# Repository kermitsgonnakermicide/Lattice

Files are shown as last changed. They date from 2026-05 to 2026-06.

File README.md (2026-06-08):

# Lattice
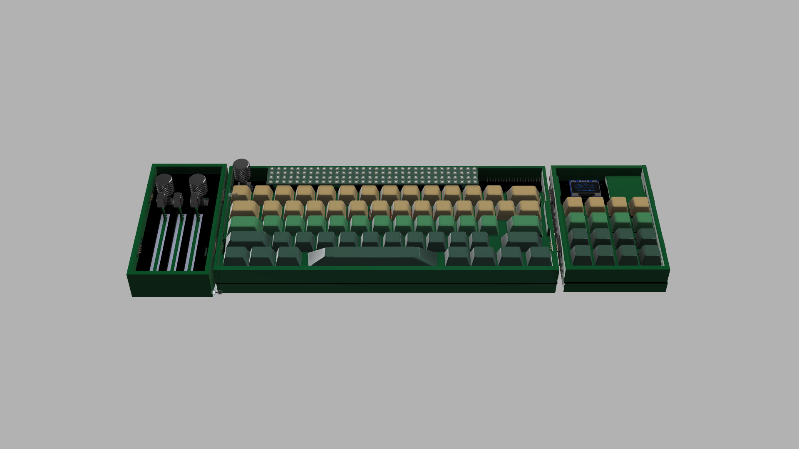
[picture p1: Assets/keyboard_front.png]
keyboard

> a 60% mechanical keyboard with magnetically attached modules

# what even is Lattice?
Lattice is a modular 60% mechanical keyboard, with the main keyboard featuring:
- cherry mx black switches
- a raspberry pi pico 2
- an EC11 encoder
- 6 expansion ports(two 2.54 inch female headers and 4 4 pin magnetic pogo connectors)
- absolutely NO RGB(in the keyboard itself skdsks)

Lattice also comes with three modules(as of now), which are:
- a 16 key macropad with an OLED
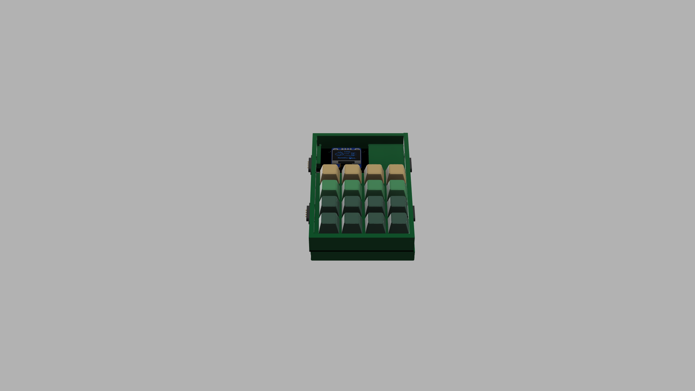
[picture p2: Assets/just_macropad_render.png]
macropad

- a 3 slider, two encoder module i'm calling the sliderpad
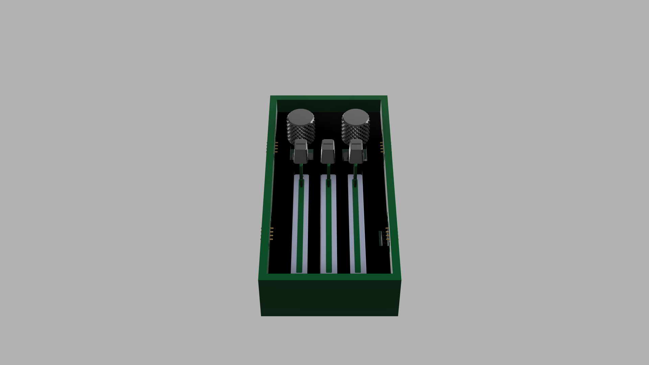
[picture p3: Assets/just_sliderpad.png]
sliderpad

- a 32x4 RGB LED(specifically the WS2812B-2020) matrix that slides in the empty top bit of the keyboard(connected by 2.54 mm pins because I didnt trust the current limits of the magnetic connectors)
matrix

Each module features a xiao rp2040 to run everything else on it because its so smol and cute :3</br>

The macropad and the sliderpad connect with magnetic pogo pins and use I2C to communicate with the main board, while the matrix does the same thing but just connects with normal pin headers and sockets. </br>

in terms of firmware, I have something basic for now - which runs each individual board and packs the data for I2C into a 16 bit struct - this wasnt really tracked as I lowk forgot and I used a bunch of AI so I wouldnt want track it anyways

# why did you even build this?(and many other whys)
I lowkenuinely just needed a keyboard pretty desperately - i've been using my crusty musty dusty redragon k552 for almost 5 years now and I need to switch it out :cryin:
additionally, I wanted a keyboard that I could actually take places, so things like a detachable cable(made possible by the pico 2) and a small form factor without compromising on key count was pretty important to me(hence the modules)

**Q: why xiao rp2040s on each board????**<br>
A: I can get them for hella cheap, they're really well documented, i've worked with them before and they're really small(works well for my purposes)

**Q: why not integrate a microcontroller on your board**<br>
A: while I would love to not use a module and put the straight microcontroller on this board, money is a problem here and I want to try and minimize costs where I can - a PCBA costs a crazy amount of money and with customs and shipping, this project aint covering it :cryin:

**Q: why not RGB?? are you not gamer???**<br>
A: i dont like RGB on the keeb - its annoying to work with, solder and must I remind you - **expensive** - to satiate the thirst for RGB i'm instead just slapping a giant matrix on the top empty bit of the board(hopefully playing snek on it soon)

# build instructions
- print out all PCBs from JLCPCB(only for the matrix PCB, use ENIG as you'll be soldering it yourself)
- get to soldering! a hot air gun/hotplate is reccomended for the matrix
- print out all parts in Production/Prints
- assemble with m3 nuts and bolts
- flash all xiao rp2040s and pico with micropython 
- on all, have boot.py and common.py and use the main.py in each folder for each respective bit 
- connect together and to your computer and start typing!
# images
<details>
<summary> Schematics </summary>

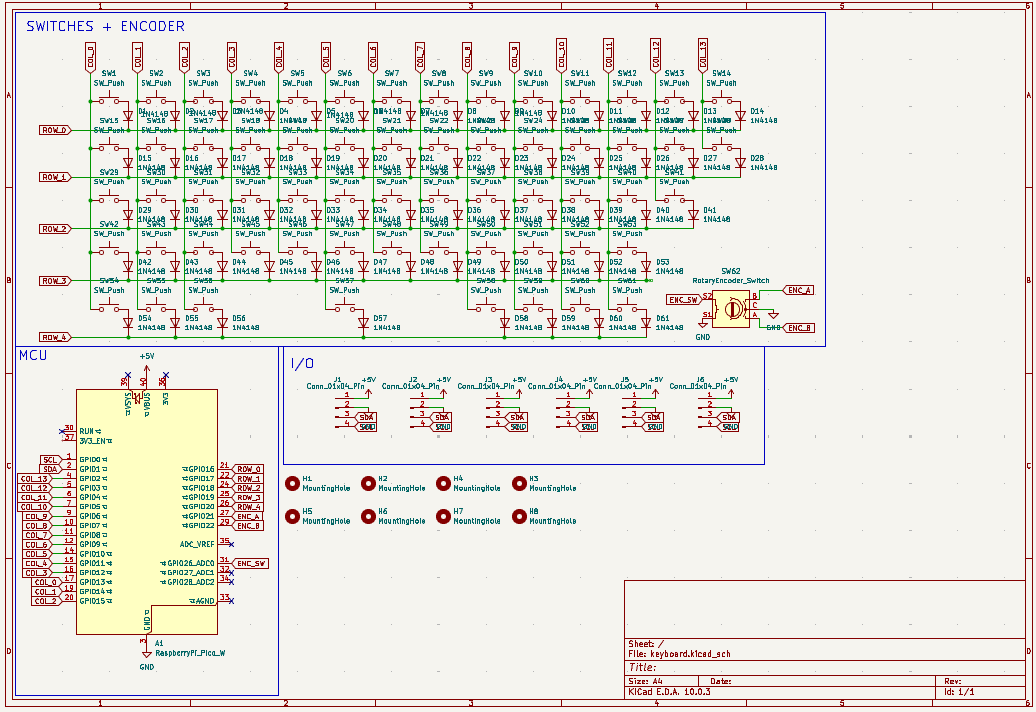
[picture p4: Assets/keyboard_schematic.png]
keyboard schematic

> main keyboard

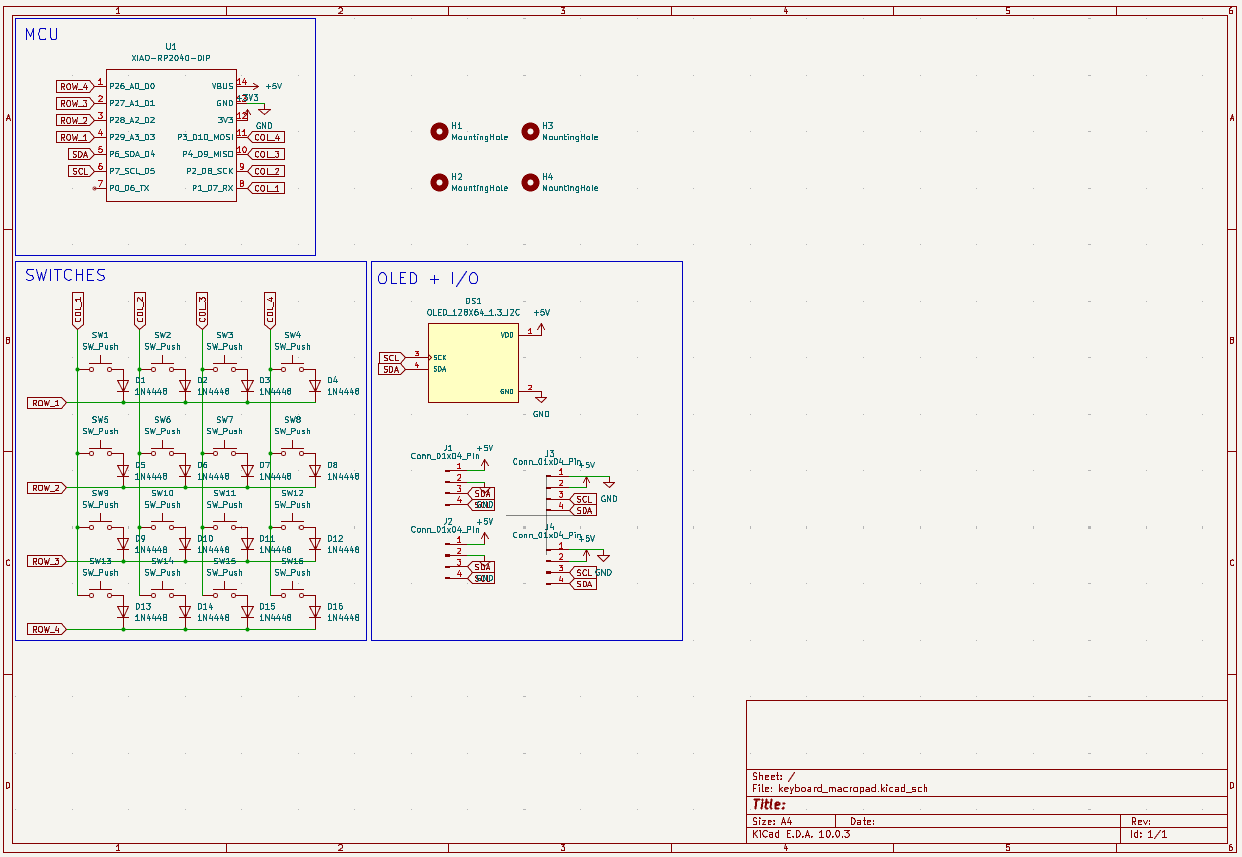
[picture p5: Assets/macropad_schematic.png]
macropad_schematic

>macropad 

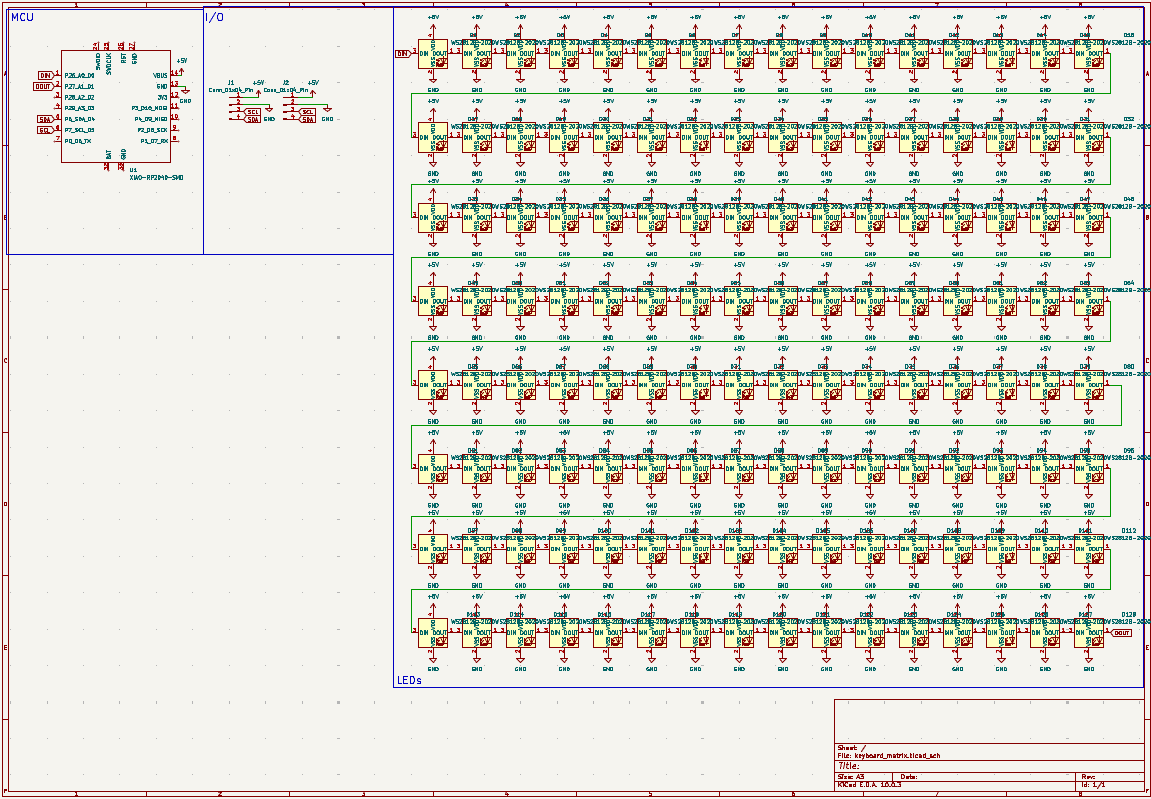
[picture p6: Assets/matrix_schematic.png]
sliderpad schematic

> sliderpad

matrix_schematic
> matrix

</details>

<details>

<summary> PCBs </summary>

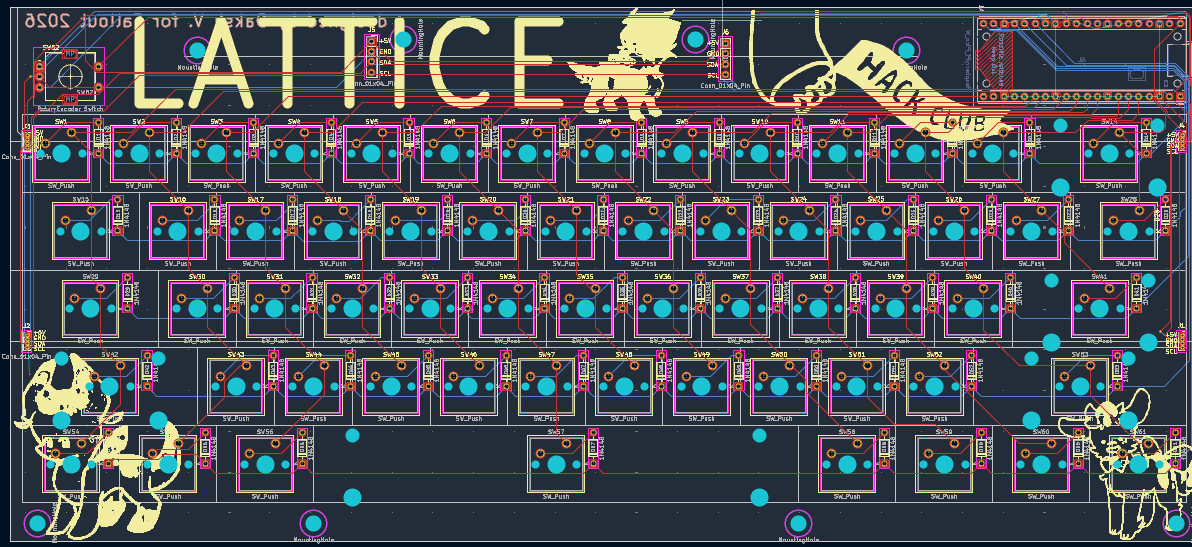
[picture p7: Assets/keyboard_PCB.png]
keyboard pcb

> main keyboard

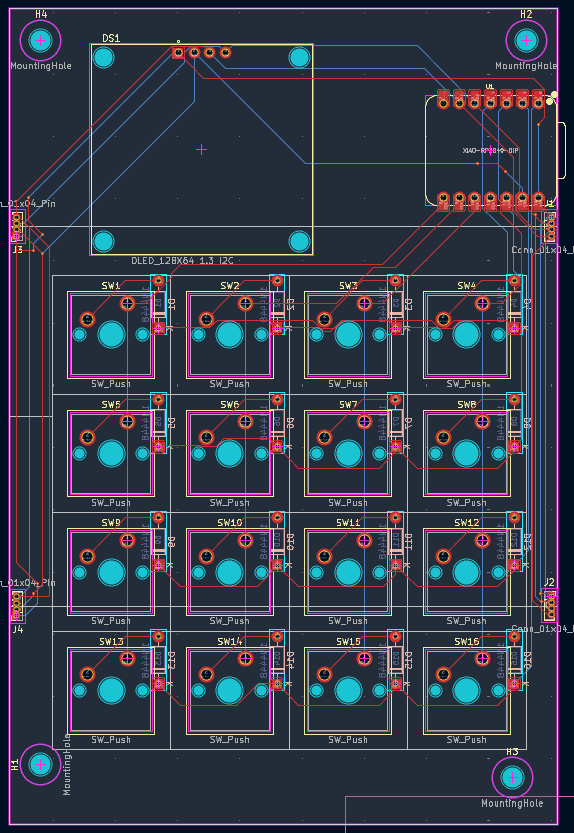
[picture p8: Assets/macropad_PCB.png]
macropad pcb

> macropad

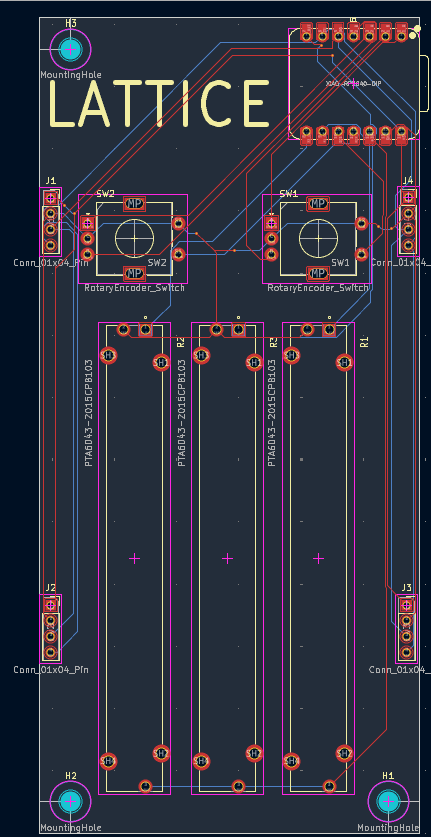
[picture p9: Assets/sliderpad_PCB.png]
sliderpad PCB

> sliderpad

matrix_pcb
> LED matrix

</details>

<details>

<summary> 3D models </summary>

keyboard pcb
> main keyboard

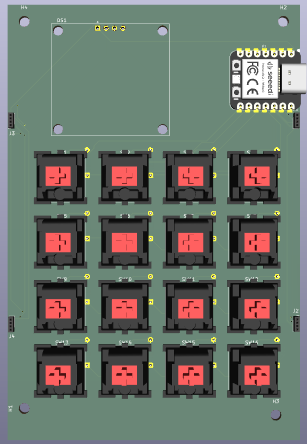
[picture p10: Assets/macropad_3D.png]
macropad pcb

> macropad

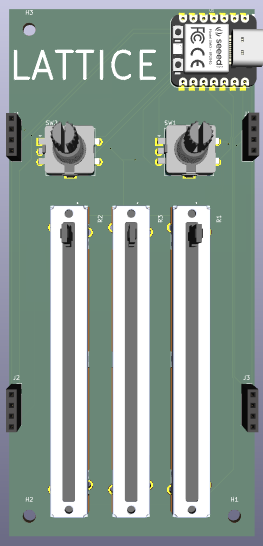
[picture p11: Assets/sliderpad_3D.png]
sliderpad PCB

> sliderpad

matrix_pcb
> LED matrix

</details>

<details>

<summary> CAD renders </summary>

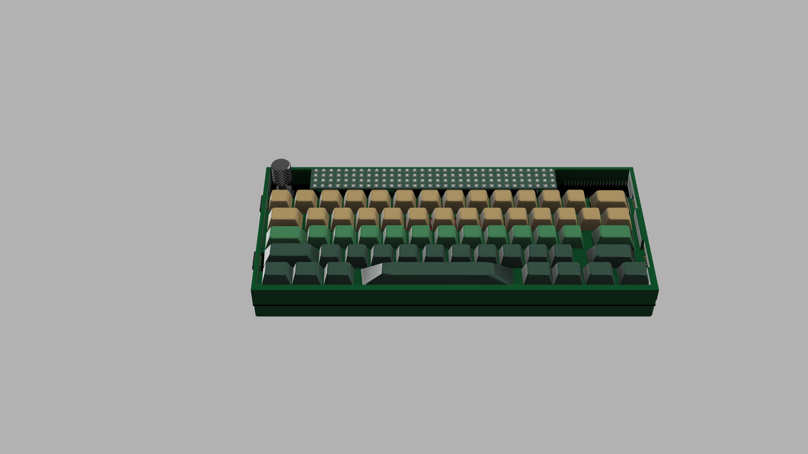
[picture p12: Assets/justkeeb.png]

> main keyboard

macropad pcb
> macropad

sliderpad PCB
> sliderpad

whole thing together
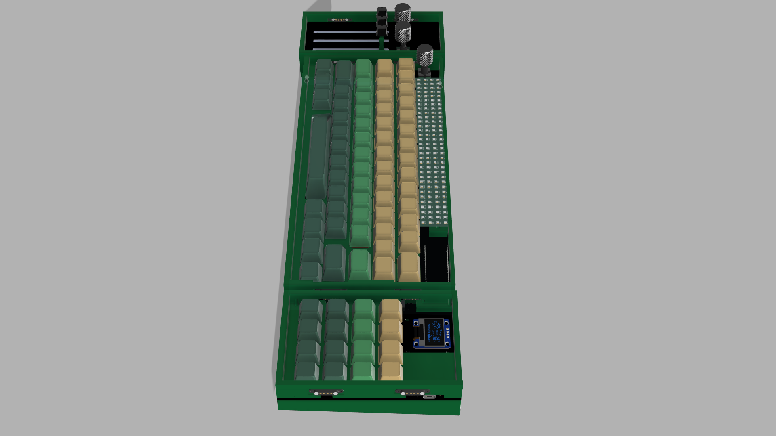
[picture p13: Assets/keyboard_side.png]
another angle

> the assembled keyboard!

</details>

# Zine

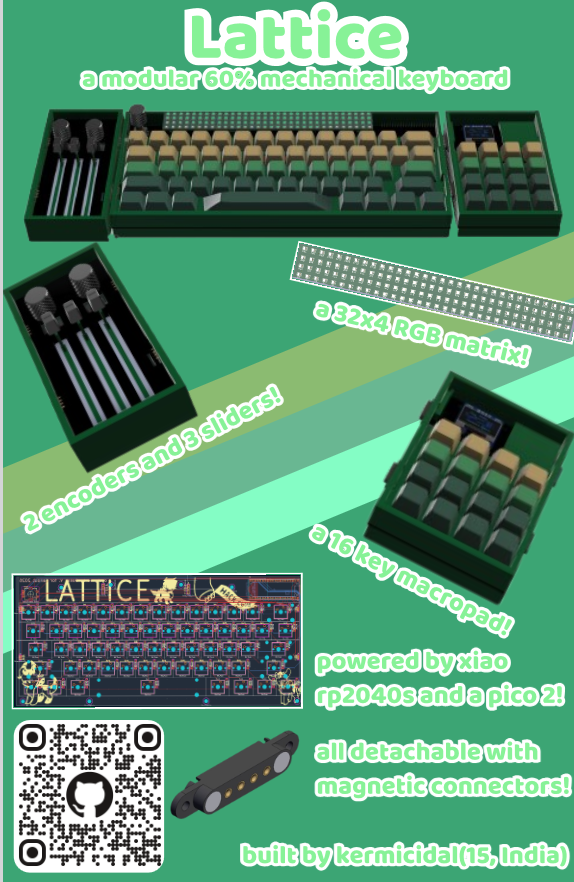
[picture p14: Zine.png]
zine


# BOM
| ITEM | LINK | UNIT PRICE | QTY  | TOTAL PRICE | RUNNING TOTAL | NOTES |
| --- | --- | --- | ---- | --- | --- | --- |
| Cherry MX Black Switches | [https://neomacro.in/products/cherry-mx-switches](https://neomacro.in/products/cherry-mx-switches) | 3.51 | 8 | 28.08 | 28.08 | pack of 10 |
| Keycap Set | [https://meckeys.com/shop/accessories/keyboard-accessories/keycaps/white-grey-keycaps/](https://meckeys.com/shop/accessories/keyboard-accessories/keycaps/white-grey-keycaps/) | 10.49 | 1 | 10.49 | 38.57 | for keyboard |
| Blank Keycaps | [https://meckeys.com/shop/accessories/keyboard-accessories/keycaps/blank/blank-dsa-keycaps-1u/](https://meckeys.com/shop/accessories/keyboard-accessories/keycaps/blank/blank-dsa-keycaps-1u/) | 1.05 | 4 | 4.2 | 42.77 | for macropad, will re-use hackpad keycaps |
| EC11 Encoders | [https://www.amazon.in/CentIoT-Encoder-Digital-Potentiometer-Control/dp/B0888RWNM1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](https://www.amazon.in/CentIoT-Encoder-Digital-Potentiometer-Control/dp/B0888RWNM1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) | 1.8 | 3 | 5.4 | 48.17 | already have |
| Slide Potentiometers | [https://www.amazon.in/Electronic-Spices-SC6080GH-Channel-Potentiometer/dp/B0BGY5C2KV?th=1](https://www.amazon.in/Electronic-Spices-SC6080GH-Channel-Potentiometer/dp/B0BGY5C2KV?th=1) | 3 | 1.68 | 5.04 | 53.21 | amazon is unfortunately the cheapest and most reliable place >:( |
| OLED | [https://robu.in/product/0-96-inch-i2c-iic-oled-lcd-module-4pin-with-vcc-gnd-blue/](https://robu.in/product/0-96-inch-i2c-iic-oled-lcd-module-4pin-with-vcc-gnd-blue/) | 2.14 | 1 | 2.14 | 55.35 | already have |
| 1N4148 diodes | [https://robu.in/product/1n4148-1w-zener-diode-pack-of-50/](https://robu.in/product/1n4148-1w-zener-diode-pack-of-50/) | 0.013 | 80 | 1.04 | 56.39 | |
| PCB | JLCPCB | 82.42 | 1 | 82.42 | 138.81 | |
| Xiao RP2040 | [https://thinkrobotics.com/products/seeed-studio-xiao-rp2040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](https://thinkrobotics.com/products/seeed-studio-xiao-rp2040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) | 5.77 | 3 | 17.31 | 156.12 | already have 2 |
| Pico 2 | [https://robu.in/product/raspberry-pi-pico-2/](https://robu.in/product/raspberry-pi-pico-2/) | 5.7 | 1 | 5.7 | 161.82 | already have 2 |
| WS2812B | [https://hubtronics.in/ws2812b-2020](https://hubtronics.in/ws2812b-2020) | 0.06 | 128  | 7.68 | 169.5 | |
| 4 pin magnetic connector pair | [https://www.flyrobo.in/4pin-pogo-magnetic-connector-pair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](https://www.flyrobo.in/4pin-pogo-magnetic-connector-pair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) | 2.06 | 4 | 8.24 | 177.74 | |
| TOTAL | | | | 0 | 177.74 | |

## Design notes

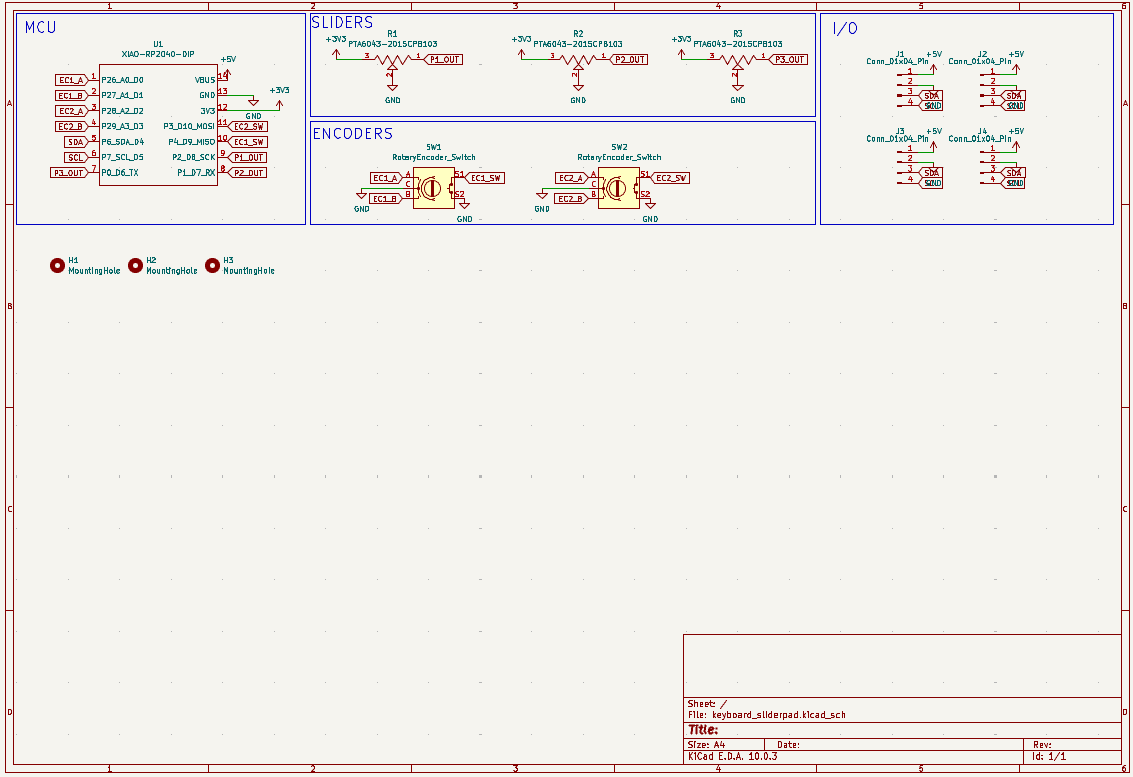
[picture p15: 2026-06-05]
Assets/sliderpad_schematic.png

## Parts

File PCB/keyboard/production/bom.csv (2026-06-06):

Designator | Footprint | Quantity | Value | LCSC Part #
A1 | RaspberryPi_Pico_Common_THT | 1 | RaspberryPi_Pico_W
D1, D10, D11, D12, D13, D14, D15, D16, D17, D18, D19, D2, D20, D21, D22, D23, D24, D25, D26, D27, D28, D29, D3, D30, D31, D32, D33, D34, D35, D36, D37, D38, D39, D4, D40, D41, D42, D43, D44, D45, D46, D47, D48, D49, D5, D50, D51, D52, D53, D54, D55, D56, D57, D58, D59, D6, D60, D61, D7, D8, D9 | D_DO-35_SOD27_P7.62mm_Horizontal | 61 | 1N4148
J1, J2, J3, J4 | PinSocket_1x04_P1.00mm_Vertical | 4 | Conn_01x04_Pin
J5, J6 | PinSocket_1x04_P2.54mm_Vertical | 2 | Conn_01x04_Pin
SW1, SW10, SW11, SW12, SW13, SW16, SW17, SW18, SW19, SW2, SW20, SW21, SW22, SW23, SW24, SW25, SW26, SW27, SW3, SW30, SW31, SW32, SW33, SW34, SW35, SW36, SW37, SW38, SW39, SW4, SW40, SW43, SW44, SW45, SW46, SW47, SW48, SW49, SW5, SW50, SW51, SW52, SW6, SW7, SW8, SW9 | jiggupiggu | 46 | SW_Push
SW14 | SW_Cherry_MX_2.00u_PCB | 1 | SW_Push
SW15, SW28 | SW_Cherry_MX_1.50u_PCB | 2 | SW_Push
SW29 | SW_Cherry_MX_1.75u_PCB | 1 | SW_Push
SW41, SW42 | SW_Cherry_MX_2.25u_PCB | 2 | SW_Push
SW53 | SW_Cherry_MX_2.75u_PCB | 1 | SW_Push
SW54, SW55, SW56, SW58, SW59, SW60, SW61 | SW_Cherry_MX_1.25u_PCB | 7 | SW_Push
SW57 | SW_Cherry_MX_6.25u_PCB | 1 | SW_Push
SW62 | RotaryEncoder_Alps_EC11E-Switch_Vertical_H20mm | 1 | RotaryEncoder_Switch

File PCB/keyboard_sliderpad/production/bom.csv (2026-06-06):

Designator | Footprint | Quantity | Value | LCSC Part #
J1, J2, J3, J4 | PinSocket_1x04_P2.54mm_Vertical | 4 | Conn_01x04_Pin
R1, R2, R3 | TRIM_PTA6043-2015CPB103 | 3 | PTA6043-2015CPB103
SW1, SW2 | RotaryEncoder_Alps_EC11E-Switch_Vertical_H20mm | 2 | RotaryEncoder_Switch
U1 | XIAO-RP2040-DIP | 1 | XIAO-RP2040-DIP

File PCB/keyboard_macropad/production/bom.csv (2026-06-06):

Designator | Footprint | Quantity | Value | LCSC Part #
D1, D10, D11, D12, D13, D14, D15, D16, D2, D3, D4, D5, D6, D7, D8, D9 | D_DO-35_SOD27_P7.62mm_Horizontal | 16 | 1N4448
DS1 | LCD_OLED_128X64_1.3_I2C | 1 | OLED_128X64_1.3_I2C
J1, J2, J3, J4 | PinSocket_1x04_P1.00mm_Vertical | 4 | Conn_01x04_Pin
SW1, SW10, SW11, SW12, SW13, SW14, SW15, SW16, SW2, SW3, SW4, SW5, SW6, SW7, SW8, SW9 | jiggupiggu | 16 | SW_Push
U1 | XIAO-RP2040-DIP | 1 | XIAO-RP2040-DIP

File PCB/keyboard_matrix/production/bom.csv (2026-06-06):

Designator | Footprint | Quantity | Value | LCSC Part #
D1, D10, D100, D101, D102, D103, D104, D105, D106, D107, D108, D109, D11, D110, D111, D112, D113, D114, D115, D116, D117, D118, D119, D12, D120, D121, D122, D123, D124, D125, D126, D127, D128, D13, D14, D15, D16, D17, D18, D19, D2, D20, D21, D22, D23, D24, D25, D26, D27, D28, D29, D3, D30, D31, D32, D33, D34, D35, D36, D37, D38, D39, D4, D40, D41, D42, D43, D44, D45, D46, D47, D48, D49, D5, D50, D51, D52, D53, D54, D55, D56, D57, D58, D59, D6, D60, D61, D62, D63, D64, D65, D66, D67, D68, D69, D7, D70, D71, D72, D73, D74, D75, D76, D77, D78, D79, D8, D80, D81, D82, D83, D84, D85, D86, D87, D88, D89, D9, D90, D91, D92, D93, D94, D95, D96, D97, D98, D99 | updatediddy | 128 | WS2812B-2020
J1, J2 | PinHeader_1x04_P2.54mm_Vertical_SMD_Pin1Right | 2 | Conn_01x04_Pin
U1 | XIAO-RP2040-SMD | 1 | XIAO-RP2040-SMD

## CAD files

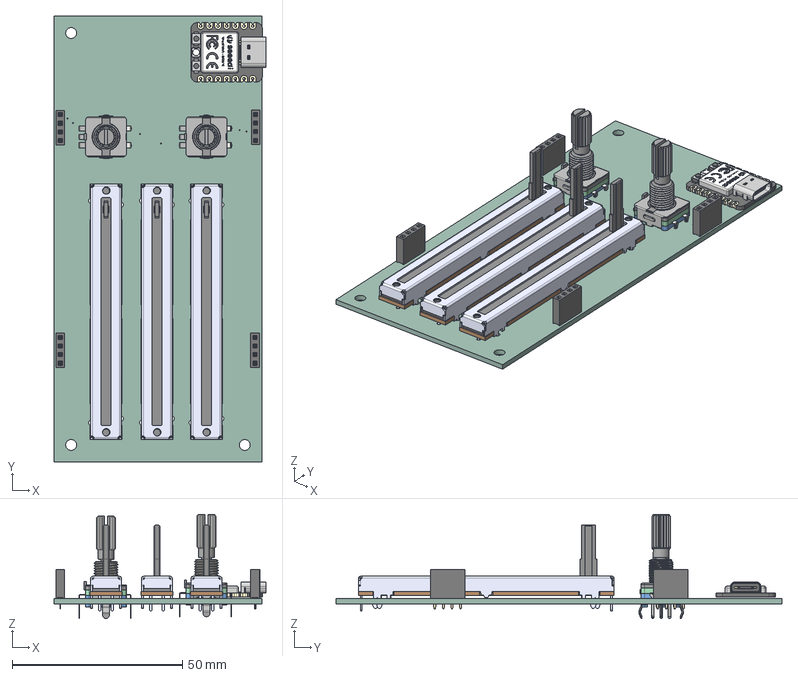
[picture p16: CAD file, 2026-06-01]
CAD/keyboard_sliderpad.step
62.2 x 131.0 x 30.6 mm
60315CP x 3
EC11_Rotary_Encoder_Switched x 2
type-c v2
smd_button v3
DOUT
DIN
VSS
VDD
smd_button v3(Mirror)
PinSocket_1x04_P2.54mm_Vertical x 4
keyboard_sliderpad_PCB

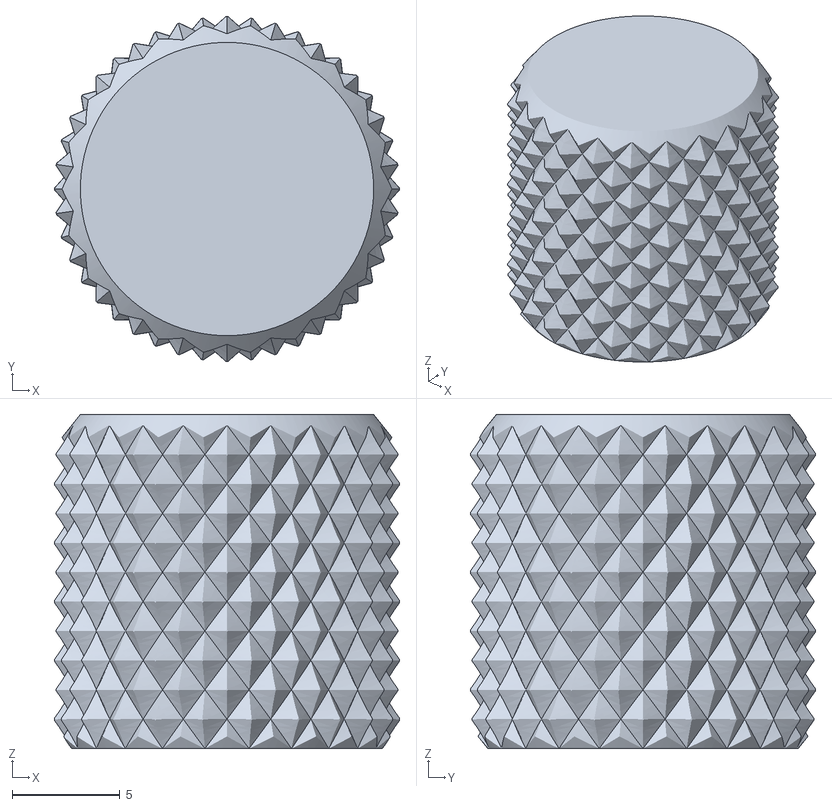
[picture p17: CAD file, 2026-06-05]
Production/Prints/rotaryKnobencoder_cap.stl
16.0 x 16.0 x 15.5

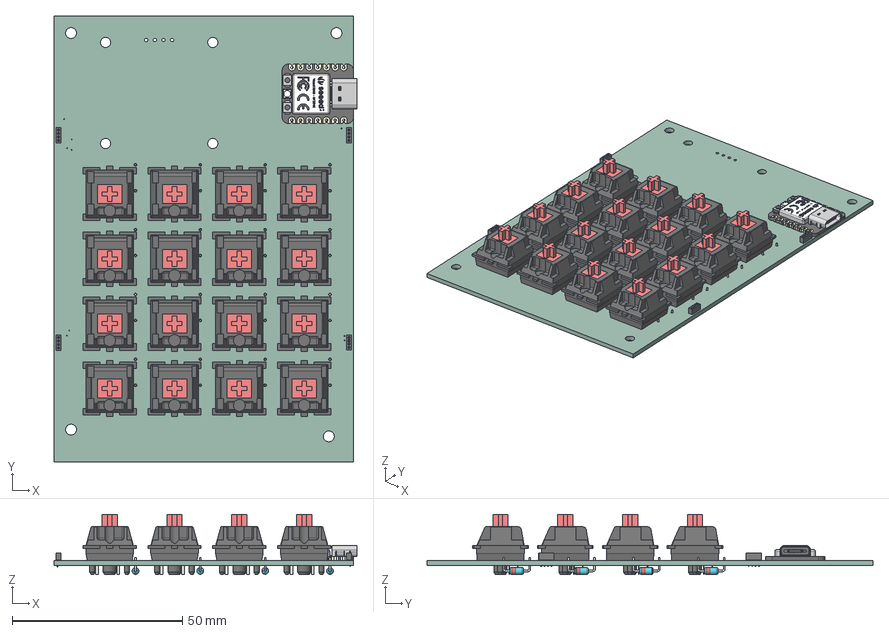
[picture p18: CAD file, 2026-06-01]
CAD/keyboard_macropad.step
89.0 x 131.0 x 17.7 mm
type-c v2
smd_button v3
DOUT
DIN
VSS
VDD
smd_button v3(Mirror)
PinSocket_1x04_P1.00mm_Vertical x 4
D_DO-35_SOD27_P7.62mm_Horizontal x 16
keyboard_macropad_PCB

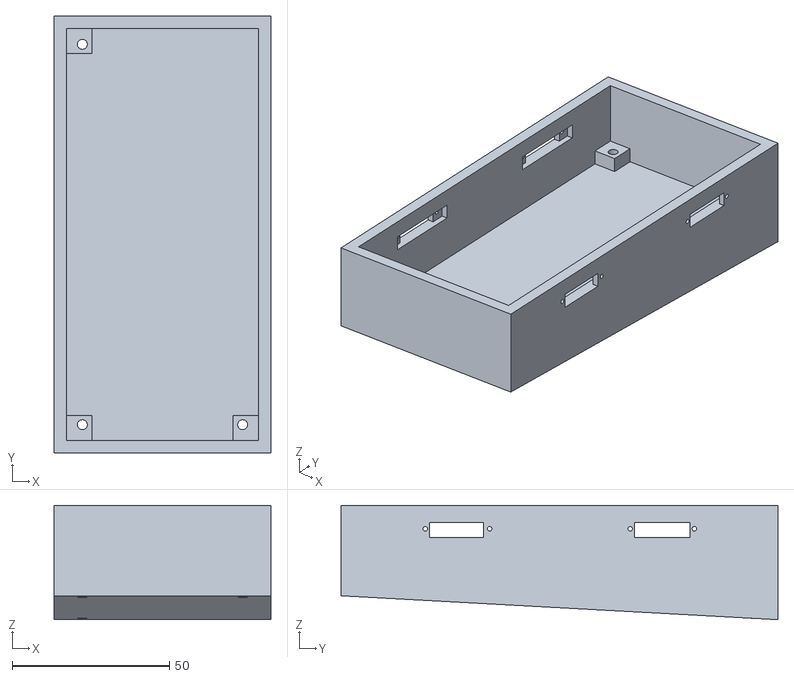
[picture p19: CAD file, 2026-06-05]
Production/Prints/sliderpad_bottomplate.stl
69.0 x 139.0 x 36.4

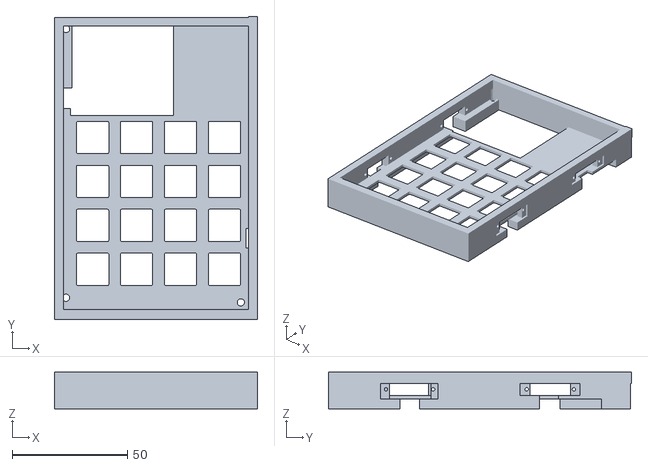
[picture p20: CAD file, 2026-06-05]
Production/Prints/macropad_topplate.stl
88.0 x 131.5 x 16.0

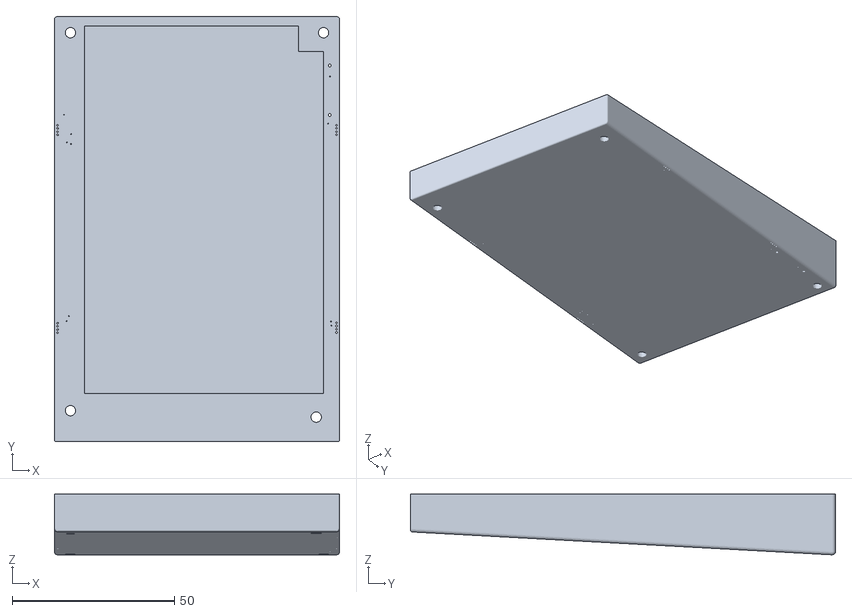
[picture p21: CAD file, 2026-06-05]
Production/Prints/macropad_bottom.stl
88.0 x 131.0 x 18.7

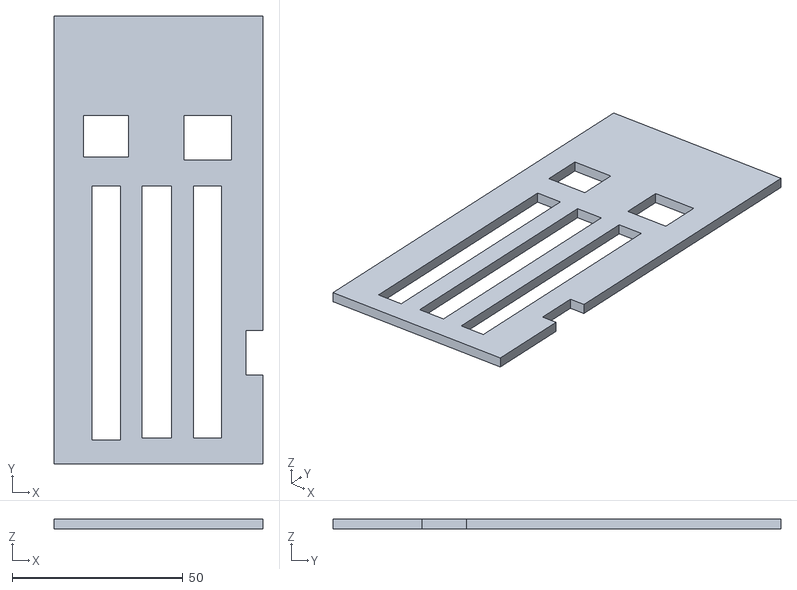
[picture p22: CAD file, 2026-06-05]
Production/Prints/sliderpad_topplate.stl
61.0 x 131.0 x 3.00

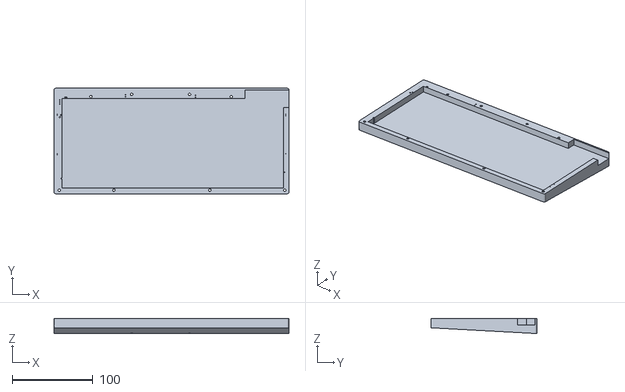
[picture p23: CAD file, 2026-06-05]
Production/Prints/keyboard_bottomplate.stl
291.4 x 131.0 x 18.7

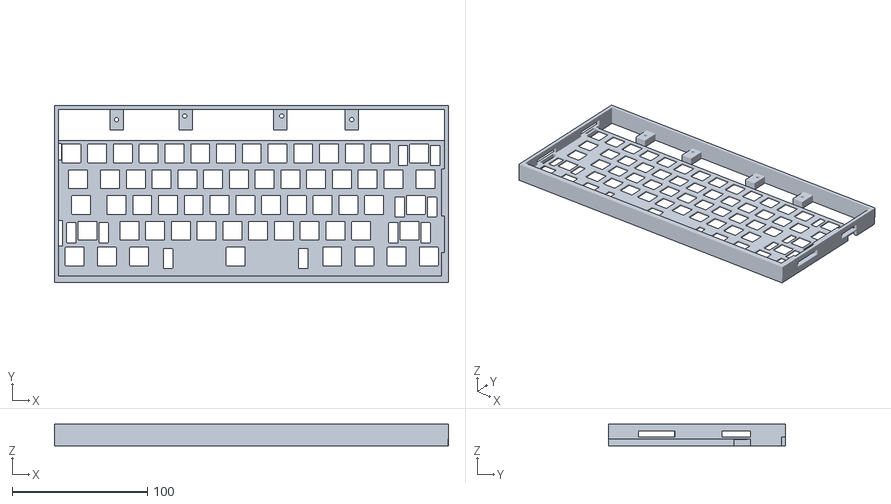
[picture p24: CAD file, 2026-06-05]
Production/Prints/keyboard_topplate.stl
291.4 x 131.0 x 16.0

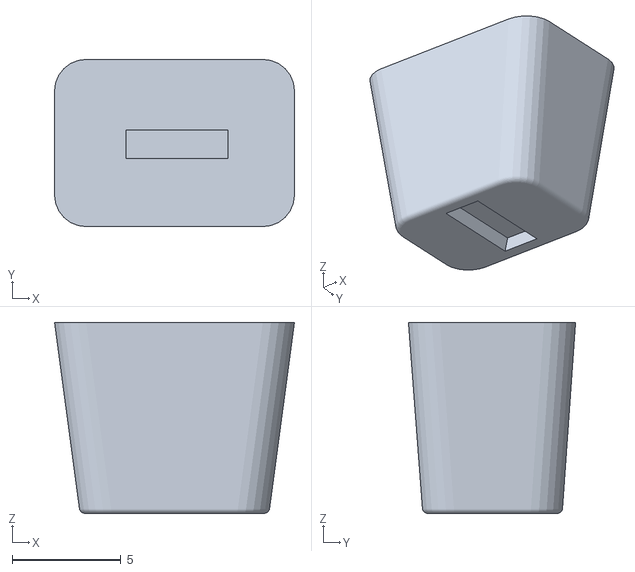
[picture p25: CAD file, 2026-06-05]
Production/Prints/001_sliderknob_v07.stl
11.0 x 7.67 x 8.78

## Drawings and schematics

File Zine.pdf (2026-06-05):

# Lattice

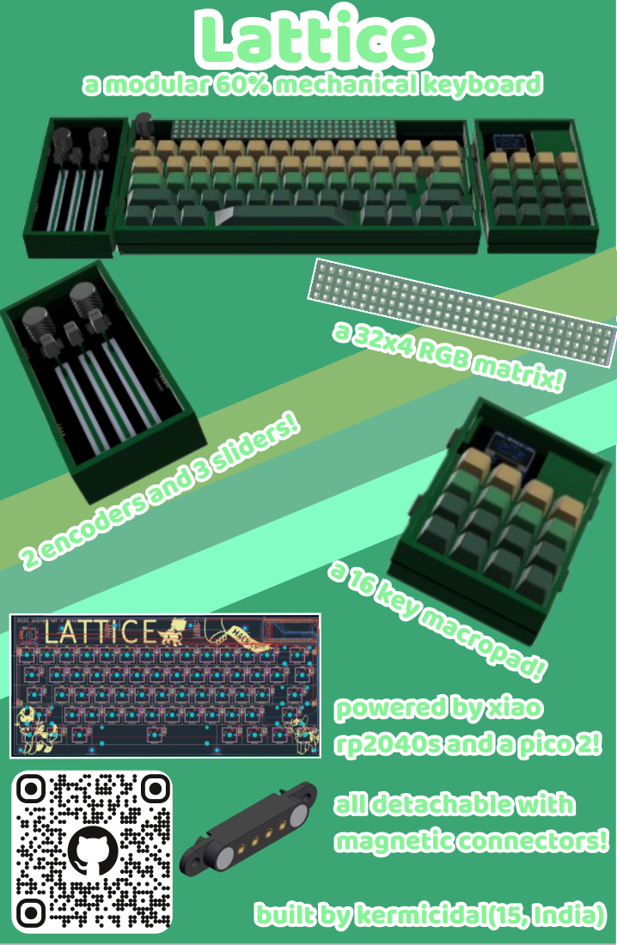
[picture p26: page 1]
a 16 key macropad!; rp2040s and a pico 2!; a 32x4 RGB matrix!; magnetic connectors!

a modular 60% mechanical keyboard

2 encoders and 3 sliders!

powered by xiao

all detachable with

built by kermicidal(15, India)

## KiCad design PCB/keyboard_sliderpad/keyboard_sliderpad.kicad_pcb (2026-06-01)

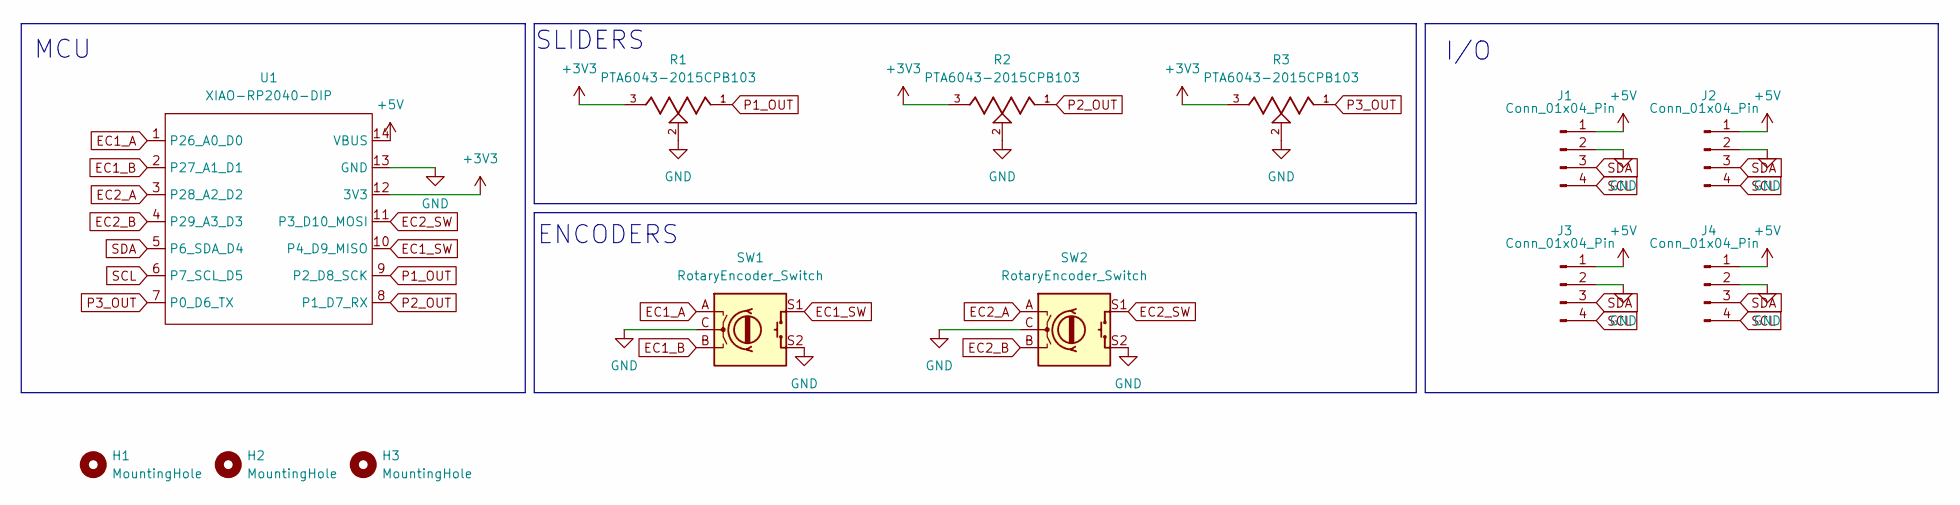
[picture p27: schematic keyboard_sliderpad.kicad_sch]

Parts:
H1, H2, H3: MountingHole; MountingHole_3.2mm_M3
J1, J2, J3, J4: Conn_01x04_Pin; PinSocket_1x04_P2.54mm_Vertical
R1, R2, R3: PTA6043-2015CPB103; TRIM_PTA6043-2015CPB103; PARTREV 04/21
SW1, SW2: RotaryEncoder_Switch; RotaryEncoder_Alps_EC11E-Switch_Vertical_H20mm
U1: XIAO-RP2040-DIP

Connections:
+3V3: R1.3, R2.3, R3.3, U1.12 (3V3)
+5V: J1.1, J2.1, J3.1, J4.1, U1.14 (VBUS)
EC1_A: SW1.A, U1.1 (P26_A0_D0)
EC1_B: SW1.B, U1.2 (P27_A1_D1)
EC1_SW: SW1.S1, U1.10 (P4_D9_MISO)
EC2_A: SW2.A, U1.3 (P28_A2_D2)
EC2_B: SW2.B, U1.4 (P29_A3_D3)
EC2_SW: SW2.S1, U1.11 (P3_D10_MOSI)
GND: J1.2, J2.2, J3.2, J4.2, R1.2, R2.2, R3.2, SW1.C, SW1.S2, SW2.C, SW2.S2, U1.13 (GND)
P1_OUT: R1.1, U1.9 (P2_D8_SCK)
P2_OUT: R2.1, U1.8 (P1_D7_RX)
P3_OUT: R3.1, U1.7 (P0_D6_TX)
SCL: J1.4, J2.4, J3.4, J4.4, U1.6 (P7_SCL_D5)
SDA: J1.3, J2.3, J3.3, J4.3, U1.5 (P6_SDA_D4)

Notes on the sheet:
MCU
SLIDERS
I/O
ENCODERS

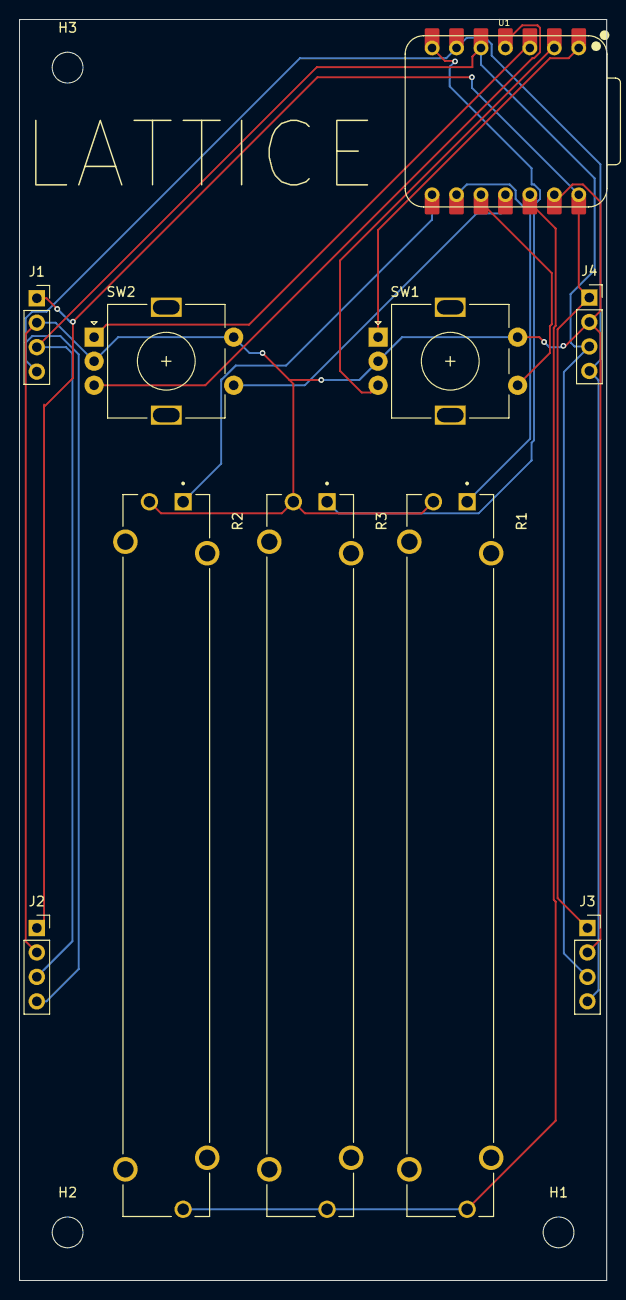
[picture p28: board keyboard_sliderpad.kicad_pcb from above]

Board: 2 copper layers, 61.0 x 131.0 mm, 13 parts (0 on the bottom side), 14 nets.

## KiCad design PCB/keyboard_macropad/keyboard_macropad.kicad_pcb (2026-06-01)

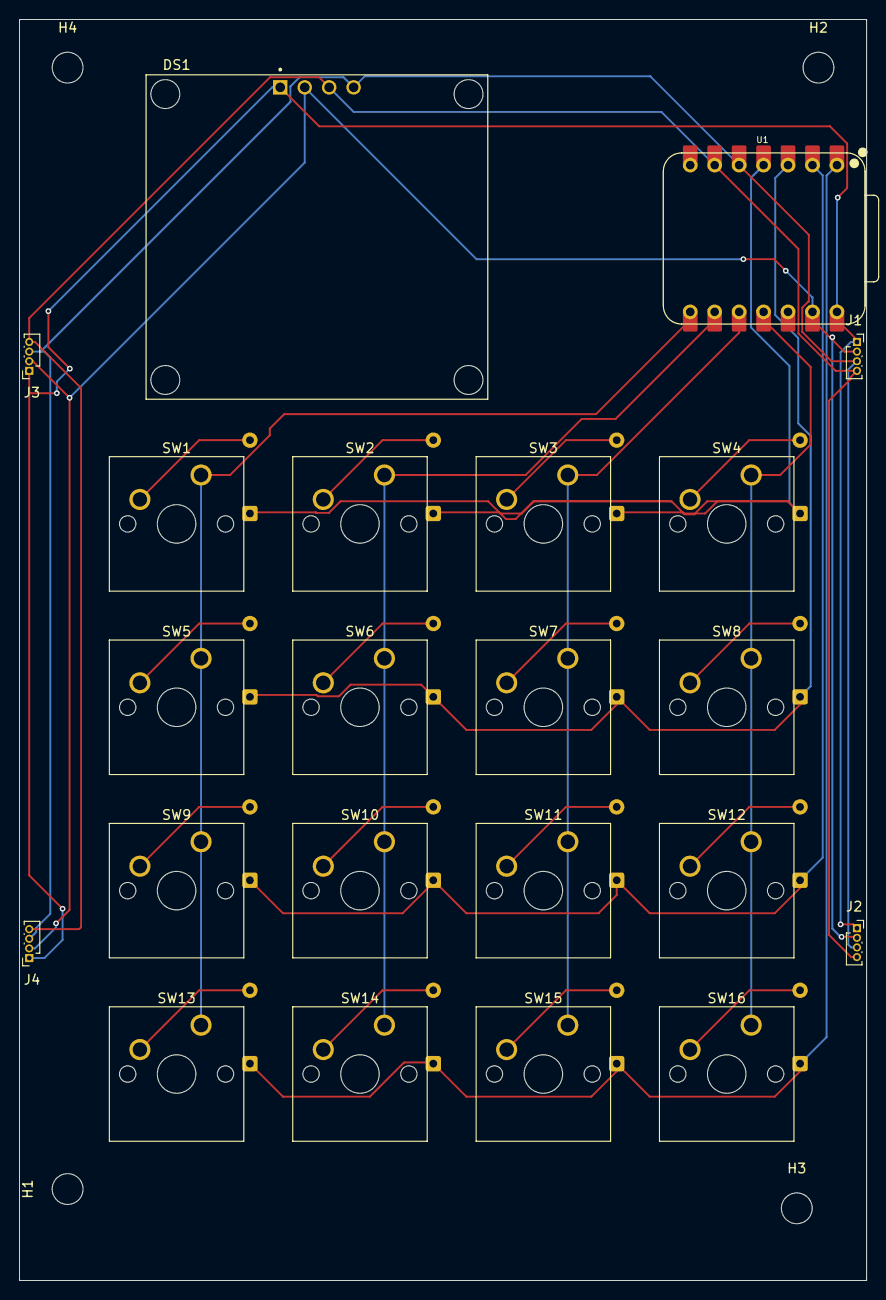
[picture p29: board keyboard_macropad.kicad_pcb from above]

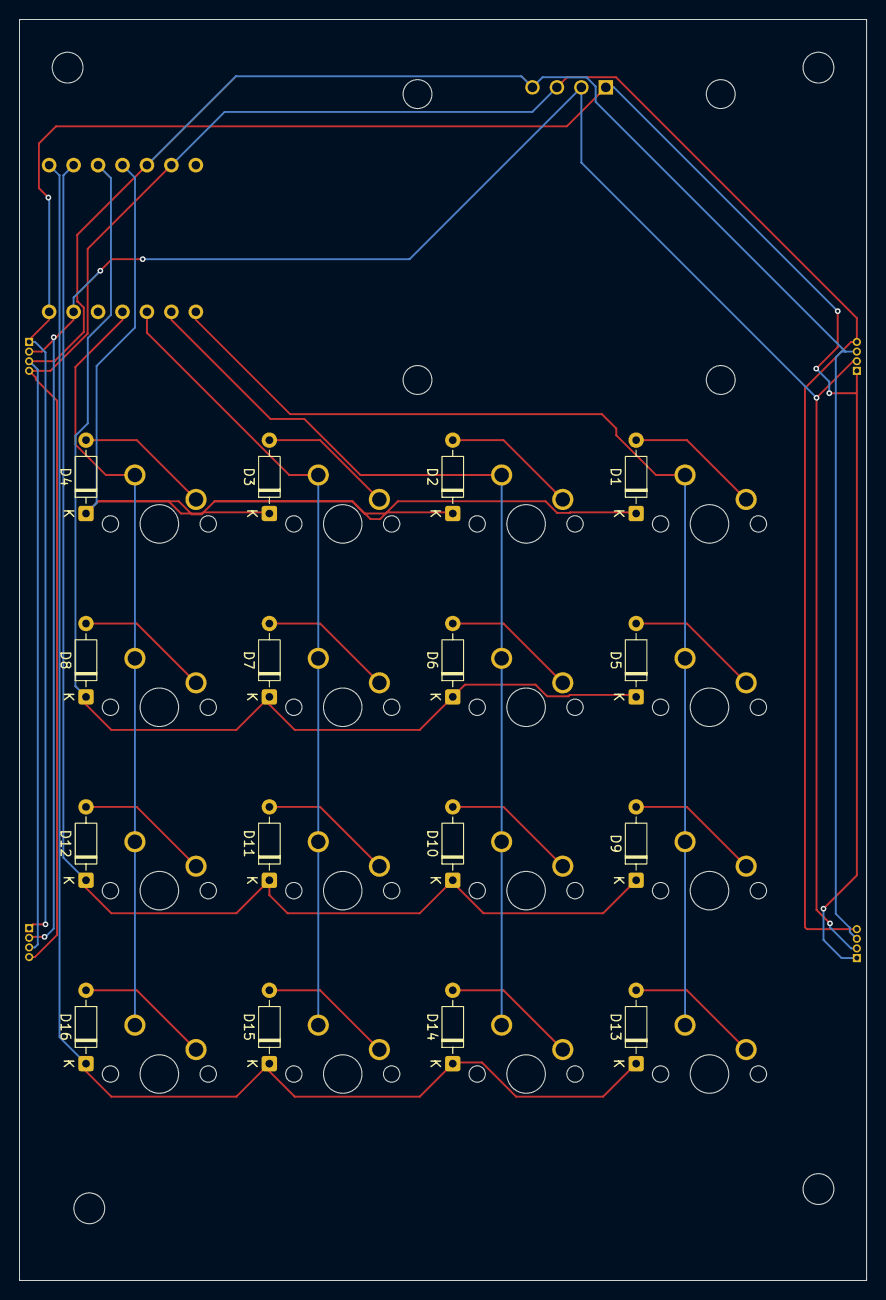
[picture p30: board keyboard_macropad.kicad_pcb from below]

Board: 2 copper layers, 88.0 x 131.0 mm, 42 parts (16 on the bottom side), 28 nets.

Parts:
D1, D2, D3, D4, D5, D6, D7, D8, D9, D10, D11, D12, D13, D14, D15, D16: 1N4448; D_DO-35_SOD27_P7.62mm_Horizontal
DS1: OLED_128X64_1.3_I2C; LCD_OLED_128X64_1.3_I2C
H1, H2, H3, H4: MountingHole; MountingHole_3.2mm_M3
J1, J2, J3, J4: Conn_01x04_Pin; PinSocket_1x04_P1.00mm_Vertical
SW1, SW2, SW3, SW4, SW5, SW6, SW7, SW8, SW9, SW10, SW11, SW12, SW13, SW14, SW15, SW16: SW_Push; jiggupiggu
U1: XIAO-RP2040-DIP

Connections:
+5V: DS1.1 (VDD), J1.1, J2.1, J3.1, J4.1, U1.14 (VBUS)
COL_1: SW1.1, SW5.1, SW9.1, SW13.1, U1.8 (P1_D7_RX)
COL_2: SW2.1, SW6.1, SW10.1, SW14.1, U1.9 (P2_D8_SCK)
COL_3: SW3.1, SW7.1, SW11.1, SW15.1, U1.10 (P4_D9_MISO)
COL_4: SW4.1, SW8.1, SW12.1, SW16.1, U1.11 (P3_D10_MOSI)
GND: DS1.2 (GND), J1.2, J2.2, J3.2, J4.2, U1.13 (GND)
unnamed: D1.2 (A), SW1.2
unnamed: D2.2 (A), SW2.2
unnamed: D3.2 (A), SW3.2
unnamed: D4.2 (A), SW4.2
unnamed: D5.2 (A), SW5.2
unnamed: D6.2 (A), SW6.2
unnamed: D7.2 (A), SW7.2
unnamed: D8.2 (A), SW8.2
unnamed: D9.2 (A), SW9.2
unnamed: D10.2 (A), SW10.2
unnamed: D11.2 (A), SW11.2
unnamed: D12.2 (A), SW12.2
unnamed: D13.2 (A), SW13.2
unnamed: D14.2 (A), SW14.2
unnamed: D15.2 (A), SW15.2
unnamed: D16.2 (A), SW16.2
ROW_1: D1.1 (K), D2.1 (K), D3.1 (K), D4.1 (K), U1.4 (P29_A3_D3)
ROW_2: D5.1 (K), D6.1 (K), D7.1 (K), D8.1 (K), U1.3 (P28_A2_D2)
ROW_3: D9.1 (K), D10.1 (K), D11.1 (K), D12.1 (K), U1.2 (P27_A1_D1)
ROW_4: D13.1 (K), D14.1 (K), D15.1 (K), D16.1 (K), U1.1 (P26_A0_D0)
SCL: DS1.3 (SCK), J1.4, J2.4, J3.4, J4.4, U1.6 (P7_SCL_D5)
SDA: DS1.4 (SDA), J1.3, J2.3, J3.3, J4.3, U1.5 (P6_SDA_D4)

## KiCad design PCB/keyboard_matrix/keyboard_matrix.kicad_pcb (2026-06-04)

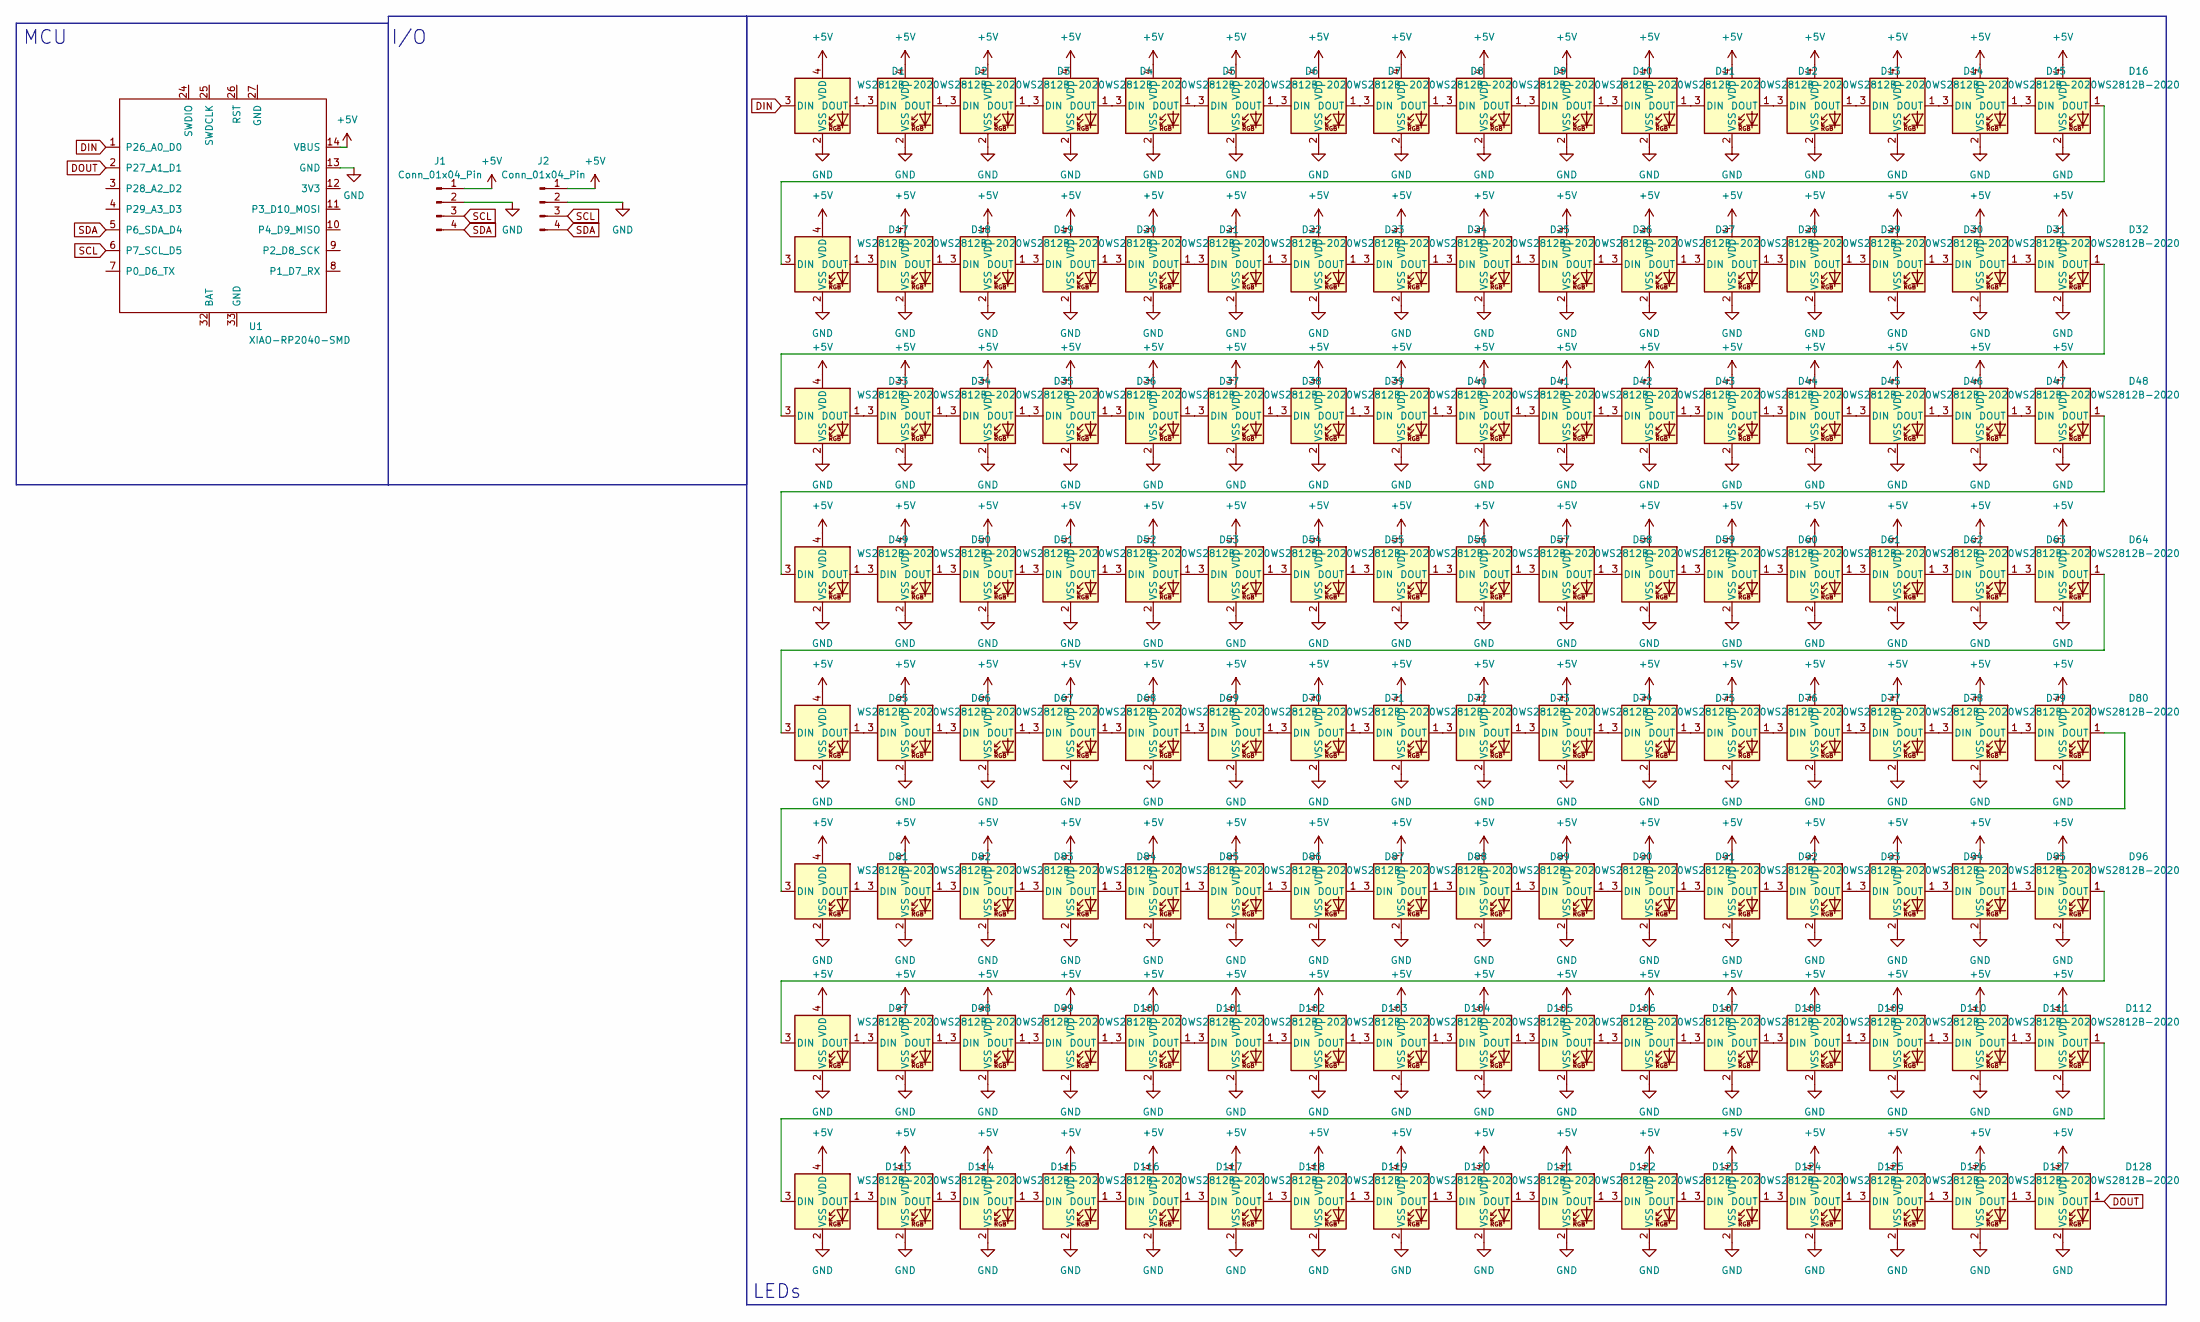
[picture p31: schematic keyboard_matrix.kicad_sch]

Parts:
D1, D2, D3, D4, D5, D6, D7, D8, D9, D10, D11, D12, D13, D14, D15, D16, D17, D18, D19, D20, D21, D22, D23, D24, D25, D26, D27, D28, D29, D30, D31, D32, D33, D34, D35, D36, D37, D38, D39, D40, D41, D42, D43, D44, D45, D46, D47, D48, D49, D50, D51, D52, D53, D54, D55, D56, D57, D58, D59, D60, D61, D62, D63, D64, D65, D66, D67, D68, D69, D70, D71, D72, D73, D74, D75, D76, D77, D78, D79, D80, D81, D82, D83, D84, D85, D86, D87, D88, D89, D90, D91, D92, D93, D94, D95, D96, D97, D98, D99, D100, D101, D102, D103, D104, D105, D106, D107, D108, D109, D110, D111, D112, D113, D114, D115, D116, D117, D118, D119, D120, D121, D122, D123, D124, D125, D126, D127, D128: WS2812B-2020; LED_WS2812B-2020_PLCC4_2.0x2.0mm
J1, J2: Conn_01x04_Pin; PinHeader_1x04_P2.54mm_Vertical_SMD_Pin1Right
U1: XIAO-RP2040-SMD

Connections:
+5V: D1.4 (VDD), D2.4 (VDD), D3.4 (VDD), D4.4 (VDD), D5.4 (VDD), D6.4 (VDD), D7.4 (VDD), D8.4 (VDD), D9.4 (VDD), D10.4 (VDD), D11.4 (VDD), D12.4 (VDD), D13.4 (VDD), D14.4 (VDD), D15.4 (VDD), D16.4 (VDD), D17.4 (VDD), D18.4 (VDD), D19.4 (VDD), D20.4 (VDD), D21.4 (VDD), D22.4 (VDD), D23.4 (VDD), D24.4 (VDD), D25.4 (VDD), D26.4 (VDD), D27.4 (VDD), D28.4 (VDD), D29.4 (VDD), D30.4 (VDD), D31.4 (VDD), D32.4 (VDD), D33.4 (VDD), D34.4 (VDD), D35.4 (VDD), D36.4 (VDD), D37.4 (VDD), D38.4 (VDD), D39.4 (VDD), D40.4 (VDD), D41.4 (VDD), D42.4 (VDD), D43.4 (VDD), D44.4 (VDD), D45.4 (VDD), D46.4 (VDD), D47.4 (VDD), D48.4 (VDD), D49.4 (VDD), D50.4 (VDD), D51.4 (VDD), D52.4 (VDD), D53.4 (VDD), D54.4 (VDD), D55.4 (VDD), D56.4 (VDD), D57.4 (VDD), D58.4 (VDD), D59.4 (VDD), D60.4 (VDD), D61.4 (VDD), D62.4 (VDD), D63.4 (VDD), D64.4 (VDD), D65.4 (VDD), D66.4 (VDD), D67.4 (VDD), D68.4 (VDD), D69.4 (VDD), D70.4 (VDD), D71.4 (VDD), D72.4 (VDD), D73.4 (VDD), D74.4 (VDD), D75.4 (VDD), D76.4 (VDD), D77.4 (VDD), D78.4 (VDD), D79.4 (VDD), D80.4 (VDD), D81.4 (VDD), D82.4 (VDD), D83.4 (VDD), D84.4 (VDD), D85.4 (VDD), D86.4 (VDD), D87.4 (VDD), D88.4 (VDD), D89.4 (VDD), D90.4 (VDD), D91.4 (VDD), D92.4 (VDD), D93.4 (VDD), D94.4 (VDD), D95.4 (VDD), D96.4 (VDD), D97.4 (VDD), D98.4 (VDD), D99.4 (VDD), D100.4 (VDD), D101.4 (VDD), D102.4 (VDD), D103.4 (VDD), D104.4 (VDD), D105.4 (VDD), D106.4 (VDD), D107.4 (VDD), D108.4 (VDD), D109.4 (VDD), D110.4 (VDD), D111.4 (VDD), D112.4 (VDD), D113.4 (VDD), D114.4 (VDD), D115.4 (VDD), D116.4 (VDD), D117.4 (VDD), D118.4 (VDD), D119.4 (VDD), D120.4 (VDD), D121.4 (VDD), D122.4 (VDD), D123.4 (VDD), D124.4 (VDD), D125.4 (VDD), D126.4 (VDD), D127.4 (VDD), D128.4 (VDD), J1.1, J2.1, U1.14 (VBUS)
DIN: D1.3 (DIN), U1.1 (P26_A0_D0)
DOUT: D128.1 (DOUT), U1.2 (P27_A1_D1)
GND: D1.2 (VSS), D2.2 (VSS), D3.2 (VSS), D4.2 (VSS), D5.2 (VSS), D6.2 (VSS), D7.2 (VSS), D8.2 (VSS), D9.2 (VSS), D10.2 (VSS), D11.2 (VSS), D12.2 (VSS), D13.2 (VSS), D14.2 (VSS), D15.2 (VSS), D16.2 (VSS), D17.2 (VSS), D18.2 (VSS), D19.2 (VSS), D20.2 (VSS), D21.2 (VSS), D22.2 (VSS), D23.2 (VSS), D24.2 (VSS), D25.2 (VSS), D26.2 (VSS), D27.2 (VSS), D28.2 (VSS), D29.2 (VSS), D30.2 (VSS), D31.2 (VSS), D32.2 (VSS), D33.2 (VSS), D34.2 (VSS), D35.2 (VSS), D36.2 (VSS), D37.2 (VSS), D38.2 (VSS), D39.2 (VSS), D40.2 (VSS), D41.2 (VSS), D42.2 (VSS), D43.2 (VSS), D44.2 (VSS), D45.2 (VSS), D46.2 (VSS), D47.2 (VSS), D48.2 (VSS), D49.2 (VSS), D50.2 (VSS), D51.2 (VSS), D52.2 (VSS), D53.2 (VSS), D54.2 (VSS), D55.2 (VSS), D56.2 (VSS), D57.2 (VSS), D58.2 (VSS), D59.2 (VSS), D60.2 (VSS), D61.2 (VSS), D62.2 (VSS), D63.2 (VSS), D64.2 (VSS), D65.2 (VSS), D66.2 (VSS), D67.2 (VSS), D68.2 (VSS), D69.2 (VSS), D70.2 (VSS), D71.2 (VSS), D72.2 (VSS), D73.2 (VSS), D74.2 (VSS), D75.2 (VSS), D76.2 (VSS), D77.2 (VSS), D78.2 (VSS), D79.2 (VSS), D80.2 (VSS), D81.2 (VSS), D82.2 (VSS), D83.2 (VSS), D84.2 (VSS), D85.2 (VSS), D86.2 (VSS), D87.2 (VSS), D88.2 (VSS), D89.2 (VSS), D90.2 (VSS), D91.2 (VSS), D92.2 (VSS), D93.2 (VSS), D94.2 (VSS), D95.2 (VSS), D96.2 (VSS), D97.2 (VSS), D98.2 (VSS), D99.2 (VSS), D100.2 (VSS), D101.2 (VSS), D102.2 (VSS), D103.2 (VSS), D104.2 (VSS), D105.2 (VSS), D106.2 (VSS), D107.2 (VSS), D108.2 (VSS), D109.2 (VSS), D110.2 (VSS), D111.2 (VSS), D112.2 (VSS), D113.2 (VSS), D114.2 (VSS), D115.2 (VSS), D116.2 (VSS), D117.2 (VSS), D118.2 (VSS), D119.2 (VSS), D120.2 (VSS), D121.2 (VSS), D122.2 (VSS), D123.2 (VSS), D124.2 (VSS), D125.2 (VSS), D126.2 (VSS), D127.2 (VSS), D128.2 (VSS), J1.2, J2.2, U1.13 (GND)
unnamed: D1.1 (DOUT), D2.3 (DIN)
unnamed: D2.1 (DOUT), D3.3 (DIN)
unnamed: D3.1 (DOUT), D4.3 (DIN)
unnamed: D4.1 (DOUT), D5.3 (DIN)
unnamed: D5.1 (DOUT), D6.3 (DIN)
unnamed: D6.1 (DOUT), D7.3 (DIN)
unnamed: D7.1 (DOUT), D8.3 (DIN)
unnamed: D8.1 (DOUT), D9.3 (DIN)
unnamed: D9.1 (DOUT), D10.3 (DIN)
unnamed: D10.1 (DOUT), D11.3 (DIN)
unnamed: D11.1 (DOUT), D12.3 (DIN)
unnamed: D12.1 (DOUT), D13.3 (DIN)
unnamed: D13.1 (DOUT), D14.3 (DIN)
unnamed: D14.1 (DOUT), D15.3 (DIN)
unnamed: D15.1 (DOUT), D16.3 (DIN)
unnamed: D16.1 (DOUT), D17.3 (DIN)
unnamed: D17.1 (DOUT), D18.3 (DIN)
unnamed: D18.1 (DOUT), D19.3 (DIN)
unnamed: D19.1 (DOUT), D20.3 (DIN)
unnamed: D20.1 (DOUT), D21.3 (DIN)
unnamed: D21.1 (DOUT), D22.3 (DIN)
unnamed: D22.1 (DOUT), D23.3 (DIN)
unnamed: D23.1 (DOUT), D24.3 (DIN)
unnamed: D24.1 (DOUT), D25.3 (DIN)
unnamed: D25.1 (DOUT), D26.3 (DIN)
unnamed: D26.1 (DOUT), D27.3 (DIN)
unnamed: D27.1 (DOUT), D28.3 (DIN)
unnamed: D28.1 (DOUT), D29.3 (DIN)
unnamed: D29.1 (DOUT), D30.3 (DIN)
unnamed: D30.1 (DOUT), D31.3 (DIN)
unnamed: D31.1 (DOUT), D32.3 (DIN)
unnamed: D32.1 (DOUT), D33.3 (DIN)
unnamed: D33.1 (DOUT), D34.3 (DIN)
unnamed: D34.1 (DOUT), D35.3 (DIN)
unnamed: D35.1 (DOUT), D36.3 (DIN)
unnamed: D36.1 (DOUT), D37.3 (DIN)
unnamed: D37.1 (DOUT), D38.3 (DIN)
unnamed: D38.1 (DOUT), D39.3 (DIN)
unnamed: D39.1 (DOUT), D40.3 (DIN)
unnamed: D40.1 (DOUT), D41.3 (DIN)
unnamed: D41.1 (DOUT), D42.3 (DIN)
unnamed: D42.1 (DOUT), D43.3 (DIN)
unnamed: D43.1 (DOUT), D44.3 (DIN)
unnamed: D44.1 (DOUT), D45.3 (DIN)
unnamed: D45.1 (DOUT), D46.3 (DIN)
unnamed: D46.1 (DOUT), D47.3 (DIN)
unnamed: D47.1 (DOUT), D48.3 (DIN)
unnamed: D48.1 (DOUT), D49.3 (DIN)
unnamed: D49.1 (DOUT), D50.3 (DIN)
unnamed: D50.1 (DOUT), D51.3 (DIN)
unnamed: D51.1 (DOUT), D52.3 (DIN)
unnamed: D52.1 (DOUT), D53.3 (DIN)
unnamed: D53.1 (DOUT), D54.3 (DIN)
unnamed: D54.1 (DOUT), D55.3 (DIN)
unnamed: D55.1 (DOUT), D56.3 (DIN)
unnamed: D56.1 (DOUT), D57.3 (DIN)
unnamed: D57.1 (DOUT), D58.3 (DIN)
unnamed: D58.1 (DOUT), D59.3 (DIN)
unnamed: D59.1 (DOUT), D60.3 (DIN)
unnamed: D60.1 (DOUT), D61.3 (DIN)
unnamed: D61.1 (DOUT), D62.3 (DIN)
unnamed: D62.1 (DOUT), D63.3 (DIN)
unnamed: D63.1 (DOUT), D64.3 (DIN)
unnamed: D64.1 (DOUT), D65.3 (DIN)
unnamed: D65.1 (DOUT), D66.3 (DIN)
unnamed: D66.1 (DOUT), D67.3 (DIN)
unnamed: D67.1 (DOUT), D68.3 (DIN)
unnamed: D68.1 (DOUT), D69.3 (DIN)
unnamed: D69.1 (DOUT), D70.3 (DIN)
unnamed: D70.1 (DOUT), D71.3 (DIN)
unnamed: D71.1 (DOUT), D72.3 (DIN)
unnamed: D72.1 (DOUT), D73.3 (DIN)
unnamed: D73.1 (DOUT), D74.3 (DIN)
unnamed: D74.1 (DOUT), D75.3 (DIN)
unnamed: D75.1 (DOUT), D76.3 (DIN)
unnamed: D76.1 (DOUT), D77.3 (DIN)
unnamed: D77.1 (DOUT), D78.3 (DIN)
unnamed: D78.1 (DOUT), D79.3 (DIN)
unnamed: D79.1 (DOUT), D80.3 (DIN)
unnamed: D80.1 (DOUT), D81.3 (DIN)
unnamed: D81.1 (DOUT), D82.3 (DIN)
unnamed: D82.1 (DOUT), D83.3 (DIN)
unnamed: D83.1 (DOUT), D84.3 (DIN)
unnamed: D84.1 (DOUT), D85.3 (DIN)
unnamed: D85.1 (DOUT), D86.3 (DIN)
unnamed: D86.1 (DOUT), D87.3 (DIN)
unnamed: D87.1 (DOUT), D88.3 (DIN)
unnamed: D88.1 (DOUT), D89.3 (DIN)
unnamed: D89.1 (DOUT), D90.3 (DIN)
unnamed: D90.1 (DOUT), D91.3 (DIN)
unnamed: D91.1 (DOUT), D92.3 (DIN)
unnamed: D92.1 (DOUT), D93.3 (DIN)
unnamed: D93.1 (DOUT), D94.3 (DIN)
unnamed: D94.1 (DOUT), D95.3 (DIN)
unnamed: D95.1 (DOUT), D96.3 (DIN)
unnamed: D96.1 (DOUT), D97.3 (DIN)
unnamed: D97.1 (DOUT), D98.3 (DIN)
unnamed: D98.1 (DOUT), D99.3 (DIN)
unnamed: D99.1 (DOUT), D100.3 (DIN)
unnamed: D100.1 (DOUT), D101.3 (DIN)
unnamed: D101.1 (DOUT), D102.3 (DIN)
unnamed: D102.1 (DOUT), D103.3 (DIN)
unnamed: D103.1 (DOUT), D104.3 (DIN)
unnamed: D104.1 (DOUT), D105.3 (DIN)
unnamed: D105.1 (DOUT), D106.3 (DIN)
unnamed: D106.1 (DOUT), D107.3 (DIN)
unnamed: D107.1 (DOUT), D108.3 (DIN)
unnamed: D108.1 (DOUT), D109.3 (DIN)
unnamed: D109.1 (DOUT), D110.3 (DIN)
unnamed: D110.1 (DOUT), D111.3 (DIN)
unnamed: D111.1 (DOUT), D112.3 (DIN)
unnamed: D112.1 (DOUT), D113.3 (DIN)
unnamed: D113.1 (DOUT), D114.3 (DIN)
unnamed: D114.1 (DOUT), D115.3 (DIN)
unnamed: D115.1 (DOUT), D116.3 (DIN)
unnamed: D116.1 (DOUT), D117.3 (DIN)
unnamed: D117.1 (DOUT), D118.3 (DIN)
unnamed: D118.1 (DOUT), D119.3 (DIN)
unnamed: D119.1 (DOUT), D120.3 (DIN)
unnamed: D120.1 (DOUT), D121.3 (DIN)
unnamed: D121.1 (DOUT), D122.3 (DIN)
unnamed: D122.1 (DOUT), D123.3 (DIN)
unnamed: D123.1 (DOUT), D124.3 (DIN)
unnamed: D124.1 (DOUT), D125.3 (DIN)
unnamed: D125.1 (DOUT), D126.3 (DIN)
unnamed: D126.1 (DOUT), D127.3 (DIN)
unnamed: D127.1 (DOUT), D128.3 (DIN)
SCL: J1.3, J2.3, U1.6 (P7_SCL_D5)
SDA: J1.4, J2.4, U1.5 (P6_SDA_D4)

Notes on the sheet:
LEDs
MCU
I/O

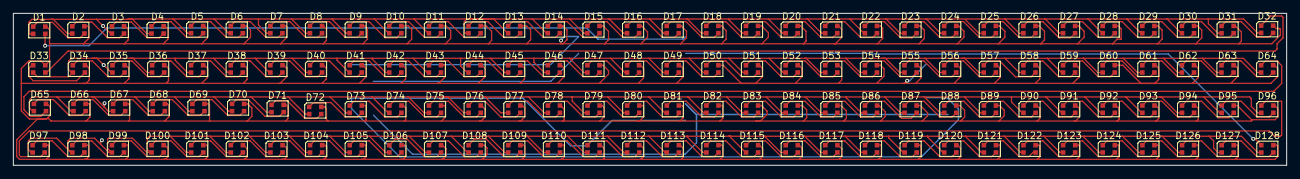
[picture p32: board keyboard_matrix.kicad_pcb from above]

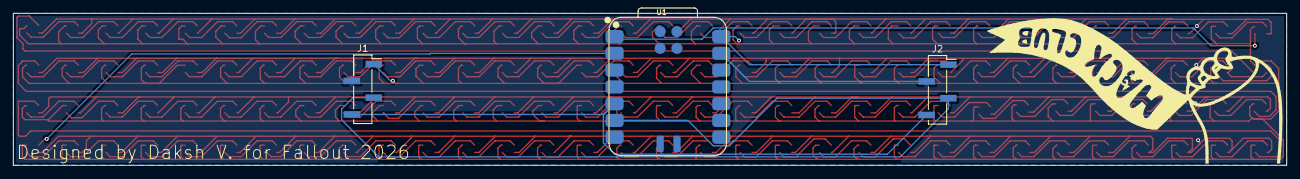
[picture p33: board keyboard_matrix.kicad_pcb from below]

Board: 2 copper layers, 192.8 x 23.0 mm, 131 parts (3 on the bottom side), 133 nets.

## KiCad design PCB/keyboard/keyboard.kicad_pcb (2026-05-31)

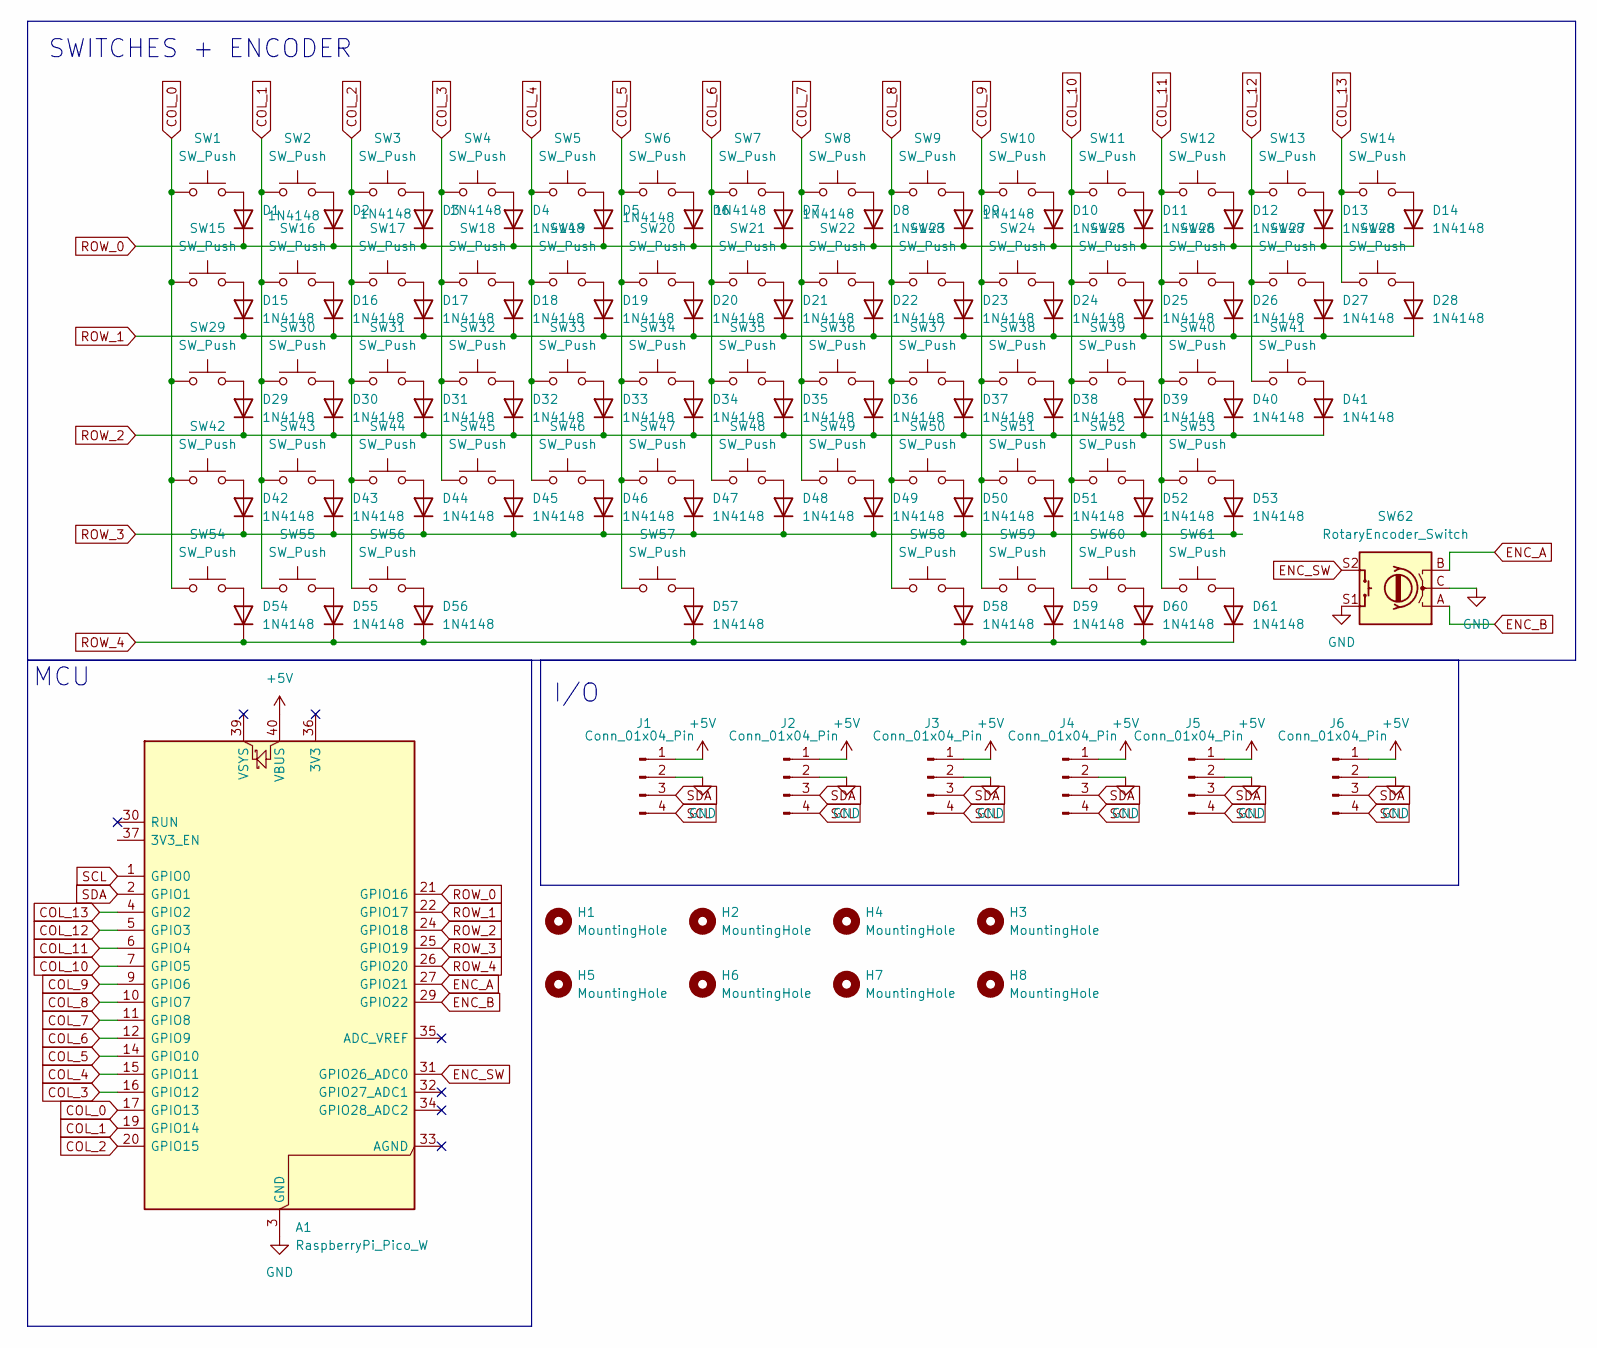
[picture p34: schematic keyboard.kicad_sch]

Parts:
A1: RaspberryPi_Pico_W; RaspberryPi_Pico_Common_THT
D1, D2, D3, D4, D5, D6, D7, D8, D9, D10, D11, D12, D13, D14, D15, D16, D17, D18, D19, D20, D21, D22, D23, D24, D25, D26, D27, D28, D29, D30, D31, D32, D33, D34, D35, D36, D37, D38, D39, D40, D41, D42, D43, D44, D45, D46, D47, D48, D49, D50, D51, D52, D53, D54, D55, D56, D57, D58, D59, D60, D61: 1N4148; D_DO-35_SOD27_P7.62mm_Horizontal
H1, H2, H3, H4, H5, H6, H7, H8: MountingHole; MountingHole_3.2mm_M3
J1, J2, J3, J4: Conn_01x04_Pin; PinSocket_1x04_P1.00mm_Vertical
J5, J6: Conn_01x04_Pin; PinSocket_1x04_P2.54mm_Vertical
SW1, SW2, SW3, SW4, SW5, SW6, SW7, SW8, SW9, SW10, SW11, SW12, SW13, SW16, SW17, SW18, SW19, SW20, SW21, SW22, SW23, SW24, SW25, SW26, SW27, SW30, SW31, SW32, SW33, SW34, SW35, SW36, SW37, SW38, SW39, SW40, SW43, SW44, SW45, SW46, SW47, SW48, SW49, SW50, SW51, SW52: SW_Push; SW_Cherry_MX_1.00u_PCB
SW14: SW_Push; SW_Cherry_MX_2.00u_PCB
SW15, SW28: SW_Push; SW_Cherry_MX_1.50u_PCB
SW29: SW_Push; SW_Cherry_MX_1.75u_PCB
SW41, SW42: SW_Push; SW_Cherry_MX_2.25u_PCB
SW53: SW_Push; SW_Cherry_MX_2.75u_PCB
SW54, SW55, SW56, SW58, SW59, SW60, SW61: SW_Push; SW_Cherry_MX_1.25u_PCB
SW57: SW_Push; SW_Cherry_MX_6.25u_PCB
SW62: RotaryEncoder_Switch; RotaryEncoder_Alps_EC11E-Switch_Vertical_H20mm

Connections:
+5V: A1.40 (VBUS), J1.1, J2.1, J3.1, J4.1, J5.1, J6.1
COL_0: A1.17 (GPIO13), SW1.1, SW15.1, SW29.1, SW42.1, SW54.1
COL_1: A1.19 (GPIO14), SW2.1, SW16.1, SW30.1, SW43.1, SW55.1
COL_2: A1.20 (GPIO15), SW3.1, SW17.1, SW31.1, SW44.1, SW56.1
COL_3: A1.16 (GPIO12), SW4.1, SW18.1, SW32.1, SW45.1
COL_4: A1.15 (GPIO11), SW5.1, SW19.1, SW33.1, SW46.1
COL_5: A1.14 (GPIO10), SW6.1, SW20.1, SW34.1, SW47.1, SW57.1
COL_6: A1.12 (GPIO9), SW7.1, SW21.1, SW35.1, SW48.1
COL_7: A1.11 (GPIO8), SW8.1, SW22.1, SW36.1, SW49.1
COL_8: A1.10 (GPIO7), SW9.1, SW23.1, SW37.1, SW50.1, SW58.1
COL_9: A1.9 (GPIO6), SW10.1, SW24.1, SW38.1, SW51.1, SW59.1
COL_10: A1.7 (GPIO5), SW11.1, SW25.1, SW39.1, SW52.1, SW60.1
COL_11: A1.6 (GPIO4), SW12.1, SW26.1, SW40.1, SW53.1, SW61.1
COL_12: A1.5 (GPIO3), SW13.1, SW27.1, SW41.1
COL_13: A1.4 (GPIO2), SW14.1, SW28.1
ENC_A: A1.27 (GPIO21), SW62.B
ENC_B: A1.29 (GPIO22), SW62.A
ENC_SW: A1.31 (GPIO26_ADC0), SW62.S2
GND: A1.3 (GND), A1.8 (GND), A1.13 (GND), A1.18 (GND), A1.23 (GND), A1.28 (GND), A1.38 (GND), J1.2, J2.2, J3.2, J4.2, J5.2, J6.2, SW62.C, SW62.S1
unnamed: D1.2 (A), SW1.2
unnamed: D2.2 (A), SW2.2
unnamed: D3.2 (A), SW3.2
unnamed: D4.2 (A), SW4.2
unnamed: D5.2 (A), SW5.2
unnamed: D6.2 (A), SW6.2
unnamed: D7.2 (A), SW7.2
unnamed: D8.2 (A), SW8.2
unnamed: D9.2 (A), SW9.2
unnamed: D10.2 (A), SW10.2
unnamed: D11.2 (A), SW11.2
unnamed: D12.2 (A), SW12.2
unnamed: D13.2 (A), SW13.2
unnamed: D14.2 (A), SW14.2
unnamed: D15.2 (A), SW15.2
unnamed: D16.2 (A), SW16.2
unnamed: D17.2 (A), SW17.2
unnamed: D18.2 (A), SW18.2
unnamed: D19.2 (A), SW19.2
unnamed: D20.2 (A), SW20.2
unnamed: D21.2 (A), SW21.2
unnamed: D22.2 (A), SW22.2
unnamed: D23.2 (A), SW23.2
unnamed: D24.2 (A), SW24.2
unnamed: D25.2 (A), SW25.2
unnamed: D26.2 (A), SW26.2
unnamed: D27.2 (A), SW27.2
unnamed: D28.2 (A), SW28.2
unnamed: D29.2 (A), SW29.2
unnamed: D30.2 (A), SW30.2
unnamed: D31.2 (A), SW31.2
unnamed: D32.2 (A), SW32.2
unnamed: D33.2 (A), SW33.2
unnamed: D34.2 (A), SW34.2
unnamed: D35.2 (A), SW35.2
unnamed: D36.2 (A), SW36.2
unnamed: D37.2 (A), SW37.2
unnamed: D38.2 (A), SW38.2
unnamed: D39.2 (A), SW39.2
unnamed: D40.2 (A), SW40.2
unnamed: D41.2 (A), SW41.2
unnamed: D42.2 (A), SW42.2
unnamed: D43.2 (A), SW43.2
unnamed: D44.2 (A), SW44.2
unnamed: D45.2 (A), SW45.2
unnamed: D46.2 (A), SW46.2
unnamed: D47.2 (A), SW47.2
unnamed: D48.2 (A), SW48.2
unnamed: D49.2 (A), SW49.2
unnamed: D50.2 (A), SW50.2
unnamed: D51.2 (A), SW51.2
unnamed: D52.2 (A), SW52.2
unnamed: D53.2 (A), SW53.2
unnamed: D54.2 (A), SW54.2
unnamed: D55.2 (A), SW55.2
unnamed: D56.2 (A), SW56.2
unnamed: D57.2 (A), SW57.2
unnamed: D58.2 (A), SW58.2
unnamed: D59.2 (A), SW59.2
unnamed: D60.2 (A), SW60.2
unnamed: D61.2 (A), SW61.2
ROW_0: A1.21 (GPIO16), D1.1 (K), D2.1 (K), D3.1 (K), D4.1 (K), D5.1 (K), D6.1 (K), D7.1 (K), D8.1 (K), D9.1 (K), D10.1 (K), D11.1 (K), D12.1 (K), D13.1 (K), D14.1 (K)
ROW_1: A1.22 (GPIO17), D15.1 (K), D16.1 (K), D17.1 (K), D18.1 (K), D19.1 (K), D20.1 (K), D21.1 (K), D22.1 (K), D23.1 (K), D24.1 (K), D25.1 (K), D26.1 (K), D27.1 (K), D28.1 (K)
ROW_2: A1.24 (GPIO18), D29.1 (K), D30.1 (K), D31.1 (K), D32.1 (K), D33.1 (K), D34.1 (K), D35.1 (K), D36.1 (K), D37.1 (K), D38.1 (K), D39.1 (K), D40.1 (K), D41.1 (K)
ROW_3: A1.25 (GPIO19), D42.1 (K), D43.1 (K), D44.1 (K), D45.1 (K), D46.1 (K), D47.1 (K), D48.1 (K), D49.1 (K), D50.1 (K), D51.1 (K), D52.1 (K), D53.1 (K)
ROW_4: A1.26 (GPIO20), D54.1 (K), D55.1 (K), D56.1 (K), D57.1 (K), D58.1 (K), D59.1 (K), D60.1 (K), D61.1 (K)
SCL: A1.1 (GPIO0), J1.4, J2.4, J3.4, J4.4, J5.4, J6.4
SDA: A1.2 (GPIO1), J1.3, J2.3, J3.3, J4.3, J5.3, J6.3

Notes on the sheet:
MCU
I/O
SWITCHES + ENCODER

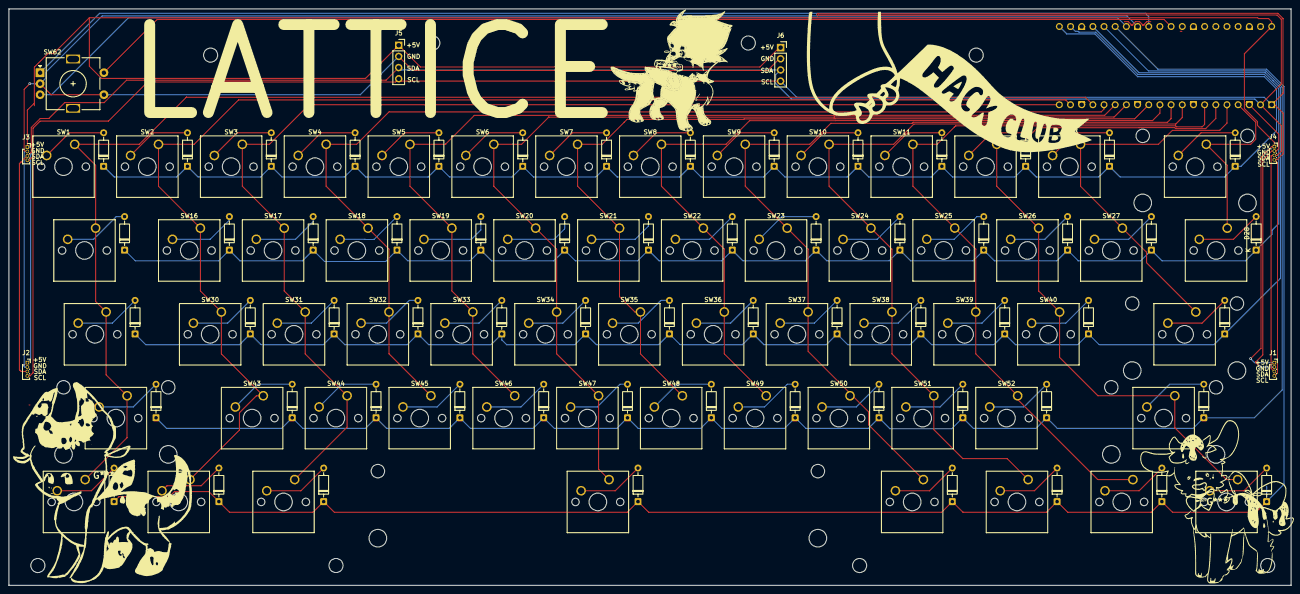
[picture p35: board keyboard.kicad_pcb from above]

Board: 2 copper layers, 291.4 x 131.0 mm, 138 parts (1 on the bottom side), 87 nets.

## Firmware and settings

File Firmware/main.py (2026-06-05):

import board
import busio
import neopixel
import supervisor
from kmk.kmk_keyboard import KMKKeyboard
from kmk.keys import KC
from kmk.modules.encoder import EncoderHandler
from kmk.modules.layers import Layers
from kmk.scanners import DiodeOrientation
from common import MACROPAD_ADDR, SLIDERPAD_ADDR, MATRIX_ADDR, PACKET_LEN, unpack_packet, clamp

keyboard = KMKKeyboard()
keyboard.col_pins = (
    board.GP7,
    board.GP8,
    board.GP9,
    board.GP10,
    board.GP11,
    board.GP12,
    board.GP13,
    board.GP14,
    board.GP15,
    board.GP16,
    board.GP17,
    board.GP18,
    board.GP19,
    board.GP20,
)
keyboard.row_pins = (board.GP2, board.GP3, board.GP4, board.GP5, board.GP6)
keyboard.diode_orientation = DiodeOrientation.COL2ROW

layers = Layers()
keyboard.modules.append(layers)

encoder_handler = EncoderHandler()
encoder_handler.pins = ((board.GP21, board.GP22, board.GP26),)
encoder_handler.map = (
    ((KC.VOLD, KC.VOLU, KC.MUTE),),
    ((KC.LEFT, KC.RIGHT, KC.MPLY),),
)
keyboard.modules.append(encoder_handler)

FN = KC.MO(1)
keyboard.keymap = [
    [
        KC.N1, KC.N2, KC.N3, KC.N4, KC.N5, KC.N6, KC.N7, KC.N8, KC.N9, KC.N0, KC.MINS, KC.EQL, KC.BSPC, KC.NO,
        KC.TAB, KC.Q, KC.W, KC.E, KC.R, KC.T, KC.Y, KC.U, KC.I, KC.O, KC.P, KC.LBRC, KC.RBRC, KC.BSLS,
        KC.ESC, KC.A, KC.S, KC.D, KC.F, KC.G, KC.H, KC.J, KC.K, KC.L, KC.SCLN, KC.QUOT, KC.ENT, KC.NO,
        KC.LSFT, KC.Z, KC.X, KC.C, KC.V, KC.B, KC.N, KC.M, KC.COMM, KC.DOT, KC.SLSH, KC.UP, KC.NO, KC.NO,
        KC.LCTL, KC.LGUI, KC.LALT, FN, KC.SPC, KC.SPC, KC.SPC, KC.SPC, KC.SPC, KC.LEFT, KC.DOWN, KC.RGHT, KC.NO, KC.NO,
    ],
    [
        KC.F1, KC.F2, KC.F3, KC.F4, KC.F5, KC.F6, KC.F7, KC.F8, KC.F9, KC.F10, KC.F11, KC.F12, KC.DEL, KC.NO,
        KC.TRNS, KC.RGB_TOG, KC.RGB_MOD, KC.RGB_HUI, KC.RGB_SAI, KC.RGB_VAI, KC.NO, KC.NO, KC.UP, KC.NO, KC.PSCR, KC.HOME, KC.END, KC.INS,
        KC.CAPS, KC.NO, KC.NO, KC.NO, KC.NO, KC.NO, KC.LEFT, KC.DOWN, KC.RIGHT, KC.NO, KC.NO, KC.NO, KC.TRNS, KC.NO,
        KC.TRNS, KC.NO, KC.NO, KC.NO, KC.NO, KC.NO, KC.NO, KC.NO, KC.NO, KC.NO, KC.NO, KC.PGUP, KC.NO, KC.NO,
        KC.TRNS, KC.TRNS, KC.TRNS, KC.TRNS, KC.TRNS, KC.TRNS, KC.TRNS, KC.TRNS, KC.TRNS, KC.HOME, KC.PGDN, KC.END, KC.NO, KC.NO,
    ],
]

i2c = busio.I2C(scl=board.GP1, sda=board.GP0, frequency=400000)
last_macropad_flags = 0
last_slider_flags = 0
last_slider_band = -1
anim_phase = 0
matrix_tx = bytearray(6)
matrix_tx[0] = 0xA5

macro_actions = {
    0: KC.LCTL(KC.C),
    1: KC.LCTL(KC.V),
    2: KC.LCTL(KC.X),
    3: KC.LCTL(KC.Z),
    4: KC.LCTL(KC.S),
    5: KC.LCTL(KC.P),
    6: KC.F13,
    7: KC.F14,
}


class ModuleState:
    def __init__(self):
        self.connected = False
        self.last_seen = 0


macropad_state = ModuleState()
sliderpad_state = ModuleState()
matrix_state = ModuleState()


def read_packet(addr):
    if not i2c.try_lock():
        return None
    raw = bytearray(PACKET_LEN)
    try:
        i2c.readfrom_into(addr, raw)
    except OSError:
        raw = None
    i2c.unlock()
    if raw is None:
        return None
    return unpack_packet(raw)


def write_matrix(mode, phase, status_bits, accent, level):
    if not i2c.try_lock():
        return
    matrix_tx[1] = mode & 0xFF
    matrix_tx[2] = phase & 0xFF
    matrix_tx[3] = status_bits & 0xFF
    matrix_tx[4] = accent & 0xFF
    matrix_tx[5] = level & 0xFF
    try:
        i2c.writeto(MATRIX_ADDR, matrix_tx)
        note_module(matrix_state)
    except OSError:
        pass
    i2c.unlock()


def tap(code):
    keyboard.tap_key(code)


def note_module(module_state):
    module_state.connected = True
    module_state.last_seen = supervisor.ticks_ms()


def clear_stale_modules():
    now = supervisor.ticks_ms()
    if now - macropad_state.last_seen > 1000:
        macropad_state.connected = False
    if now - sliderpad_state.last_seen > 1000:
        sliderpad_state.connected = False
    if now - matrix_state.last_seen > 1000:
        matrix_state.connected = False


def handle_macropad(packet):
    global last_macropad_flags
    note_module(macropad_state)
    rising = packet['flags'] & ~last_macropad_flags
    last_macropad_flags = packet['flags']
    for bit, keycode in macro_actions.items():
        if rising & (1 << bit):
            tap(keycode)


slider_map = {
    0: KC.MPRV,
    1: None,
    2: KC.MPLY,
    3: KC.MNXT,
}


def slider_band(value):
    return clamp(value // 1024, 0, 3)


def handle_sliderpad(packet):
    global last_slider_flags, last_slider_band
    note_module(sliderpad_state)
    changed = packet['flags'] ^ last_slider_flags
    pressed = packet['flags']
    last_slider_flags = packet['flags']

    if changed & 0x01 and pressed & 0x01:
        tap(KC.MPLY)
    if changed & 0x02 and pressed & 0x02:
        tap(KC.MNXT)
    if changed & 0x10:
        tap(KC.VOLU)
    if changed & 0x20:
        tap(KC.VOLD)
    if changed & 0x40:
        tap(KC.RIGHT)
    if changed & 0x80:
        tap(KC.LEFT)

    band = slider_band(packet['value0'])
    if band != last_slider_band:
        last_slider_band = band
        action = slider_map.get(band)
        if action is not None:
            tap(action)


def update_matrix_module():
    # mode 1 for default layer, mode 2 for function layer
    mode = 1 if keyboard.active_layers[0] == 0 else 2
    status_bits = 0
    if macropad_state.connected:
        status_bits |= 0x01
    if sliderpad_state.connected:
        status_bits |= 0x02
    if matrix_state.connected:
        status_bits |= 0x04
    accent = last_slider_band if last_slider_band >= 0 else 0
    write_matrix(mode, anim_phase, status_bits, accent, 24)


def animate_matrix():
    global anim_phase
    anim_phase = (anim_phase + 1) & 0xFF
    update_matrix_module()


def after_matrix_scan(_):
    packet = read_packet(MACROPAD_ADDR)
    if packet and packet['id'] == 1:
        handle_macropad(packet)

    packet = read_packet(SLIDERPAD_ADDR)
    if packet and packet['id'] == 2:
        handle_sliderpad(packet)

    clear_stale_modules()

    if supervisor.ticks_ms() % 24 < 4:
        animate_matrix()


keyboard.after_matrix_scan = after_matrix_scan
keyboard.go()

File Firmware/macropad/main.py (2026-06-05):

import board
import busio
import displayio
import terminalio
from adafruit_display_text import label
from adafruit_displayio_ssd1306 import SSD1306
from digitalio import DigitalInOut, Direction, Pull
import i2ctarget
from common import make_packet

ROWS = (board.GP0, board.GP1, board.GP2, board.GP3)
COLS = (board.GP4, board.GP5, board.GP6, board.GP7)
OLED_SDA = board.GP8
OLED_SCL = board.GP9
packet = make_packet(1)

displayio.release_displays()
i2c = busio.I2C(scl=OLED_SCL, sda=OLED_SDA, frequency=400000)
display_bus = displayio.I2CDisplay(i2c, device_address=0x3C)
display = SSD1306(display_bus, width=128, height=64)
root = displayio.Group()
root.append(label.Label(terminalio.FONT, text='lattice macropad', x=0, y=8))
count_label = label.Label(terminalio.FONT, text='keys: 0', x=0, y=20)
root.append(count_label)
cell_tiles = []
for idx in range(16):
    x = (idx % 4) * 30
    y = 28 + (idx // 4) * 9
    bmp = displayio.Bitmap(24, 7, 2)
    pal = displayio.Palette(2)
    pal[0] = 0x000000
    pal[1] = 0xFFFFFF
    tile = displayio.TileGrid(bmp, pixel_shader=pal, x=x, y=y)
    root.append(tile)
    cell_tiles.append(bmp)
display.root_group = root

rows = []
cols = []
for pin in ROWS:
    io = DigitalInOut(pin)
    io.direction = Direction.OUTPUT
    io.value = True
    rows.append(io)
for pin in COLS:
    io = DigitalInOut(pin)
    io.direction = Direction.INPUT
    io.pull = Pull.UP
    cols.append(io)


def popcount(value):
    count = 0
    while value:
        count += value & 1
        value >>= 1
    return count


def scan_keys():
    mask = 0
    for r, row in enumerate(rows):
        row.value = False
        for c, col in enumerate(cols):
            if not col.value:
                mask |= 1 << (r * 4 + c)
        row.value = True
    return mask


def draw_cells(mask):
    count_label.text = 'keys: {}'.format(popcount(mask))
    for idx, bmp in enumerate(cell_tiles):
        pressed = bool(mask & (1 << idx))
        for x in range(24):
            for y in range(7):
                edge = x == 0 or x == 23 or y == 0 or y == 6
                fill = pressed and 1 < x < 22 and 1 < y < 5
                bmp[x, y] = 1 if edge or fill else 0


def refresh_packet(mask):
    packet[7] = mask & 0xFF


def module_packet():
    return packet


last_mask = -1

with i2ctarget.I2CTarget(board.GP27, board.GP26, (0x31,)) as device:
    while True:
        mask = scan_keys()
        if mask != last_mask:
            refresh_packet(mask)
            draw_cells(mask)
            last_mask = mask

        r = device.request()
        if r:
            with r:
                if r.is_read:
                    r.write(packet)

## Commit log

2026-06-05 full re-org + readme updates
    [001_sliderknob_v07.stl, keyboard.kicad_pcb, keyboard.kicad_sch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]
2026-06-06 oops forgot to commit BOM
    [BOM.csv, bom.csv, designators.csv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]
2026-06-08 BOM issue
    [BOM.csv]
2026-06-08 fix BOM
